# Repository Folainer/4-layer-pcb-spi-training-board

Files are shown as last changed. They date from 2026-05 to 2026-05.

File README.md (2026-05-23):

# 4-Layer SPI-Based Multi-Function PCB Design (Training Project)

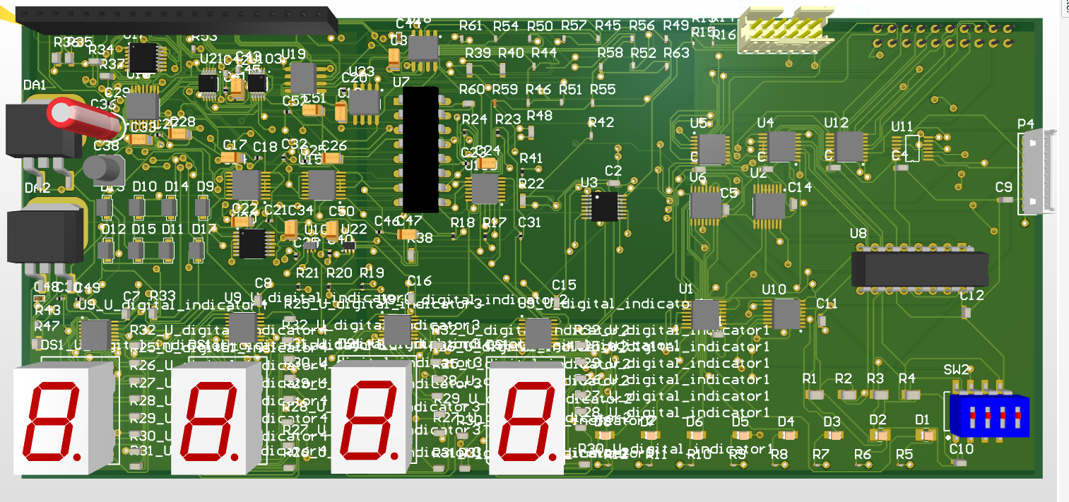
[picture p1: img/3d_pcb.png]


[Project Schematic (PDF)](./docs/Schematic%20PDF_[No%20Variations].pdf)

### Overview
This project presents the design of a **4-layer printed circuit board (PCB)** developed as a training platform for learning modern hardware design practices.

The board is designed to interface with an external SPI master device (conceptually) and integrates multiple digital and analog subsystems. The primary goal of this project is not a single application, but rather gaining hands-on experience in full-cycle PCB development.

---

### Features
- SPI-based communication interface (conceptual master-slave setup)
- LED and 7-segment display control
- Matrix keyboard input handling
- Shift registers integration
- Analog signal processing using operational amplifiers
- ADC (Analog-to-Digital Converter)
- DAC (Digital-to-Analog Converter)

---

### Hardware Architecture
The design combines both **digital logic (74HC series)** and **analog components**, including:
- Counters, shift registers, multiplexers
- Operational amplifiers (MCP600x series)
- ADC (ADS8867)
- DAC (TLV5604)

The system is modular and demonstrates interaction between multiple subsystems via SPI.

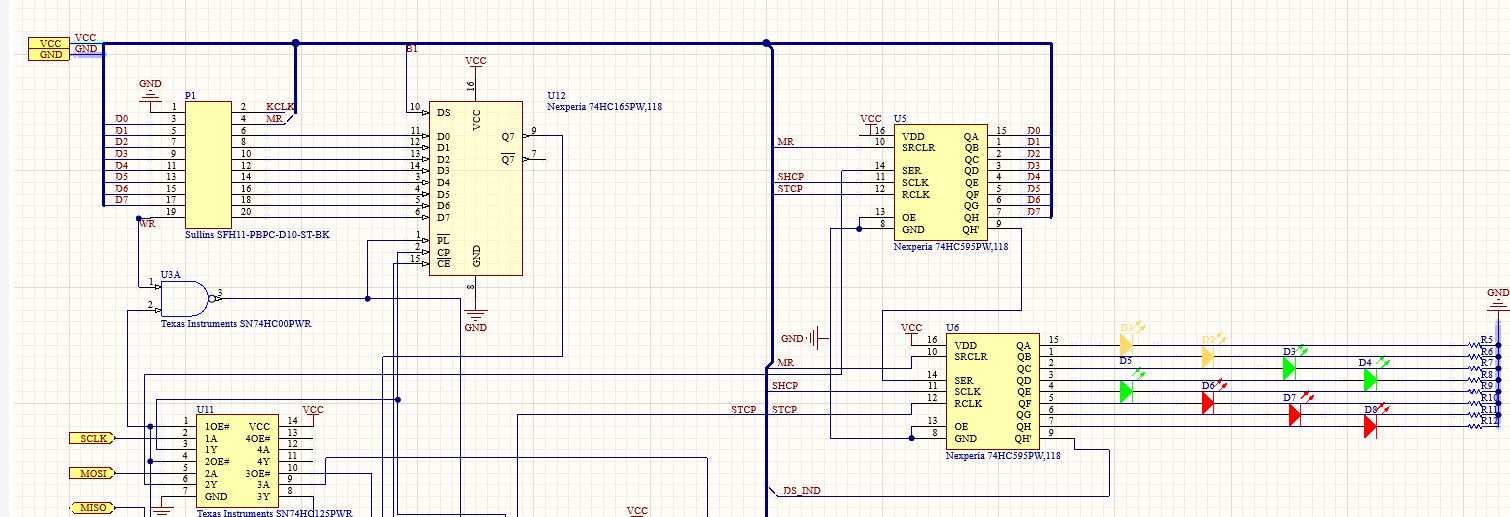
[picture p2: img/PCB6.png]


---

### PCB Design
- **4-layer PCB stackup**
    - Top Layer — signal routing
    - Inner Layer 1 — power plane (5V / 3.3V)
    - Inner Layer 2 — ground plane
    - Bottom Layer — signal routing
- Separation of **analog and digital domains**
- Star grounding technique (single-point ground connection)
- Power polygons for multiple voltage domains
- Priority-based manual routing for critical signals
- Basic impedance awareness and EMI reduction techniques

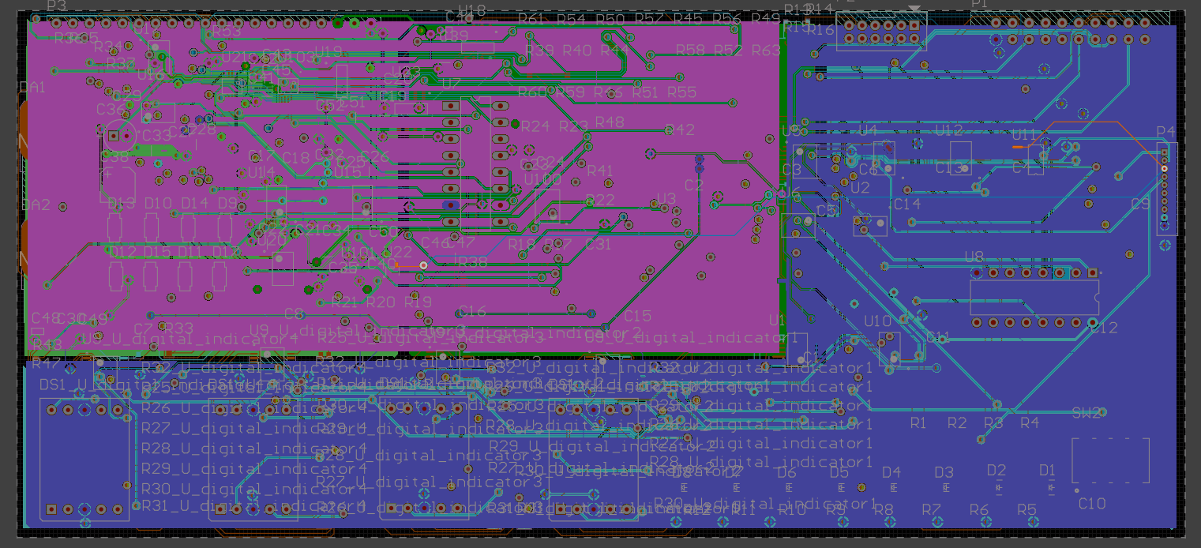
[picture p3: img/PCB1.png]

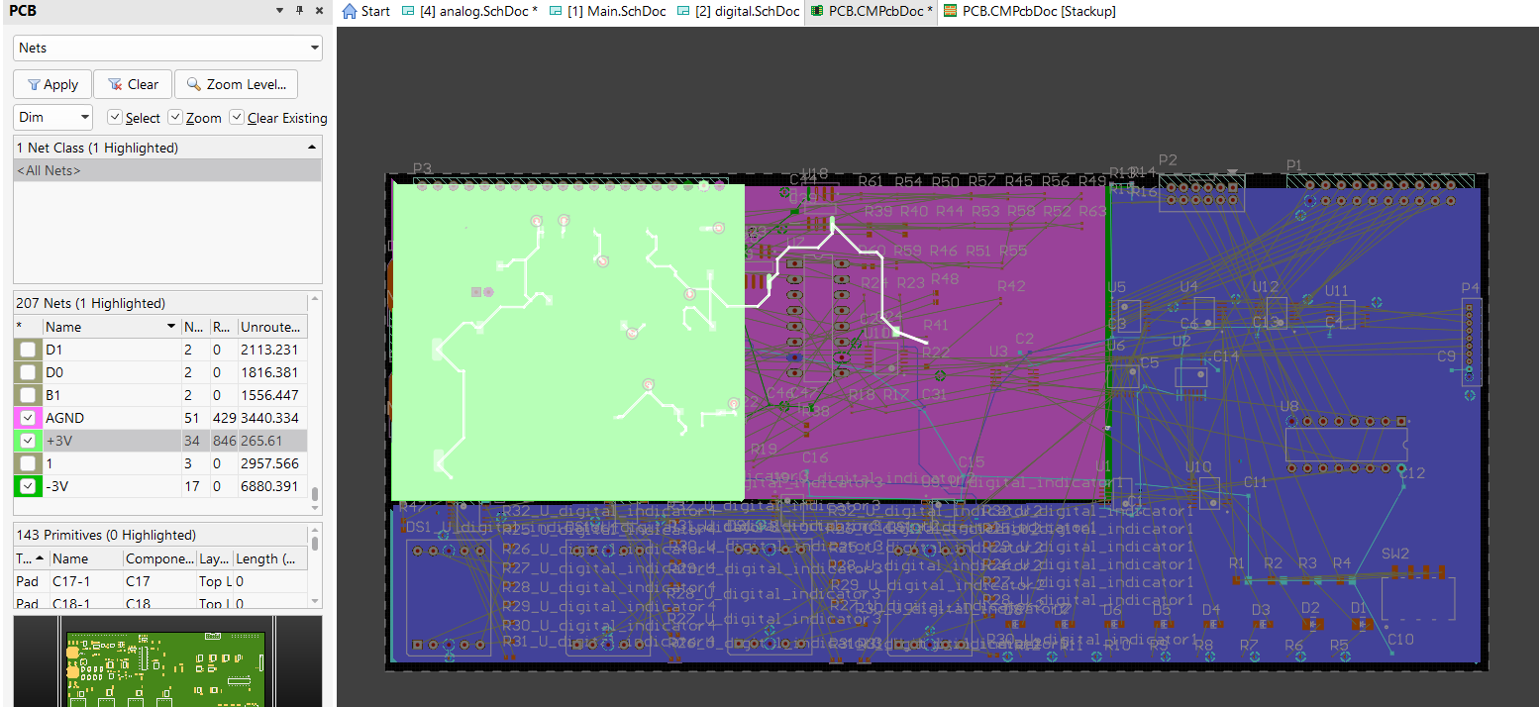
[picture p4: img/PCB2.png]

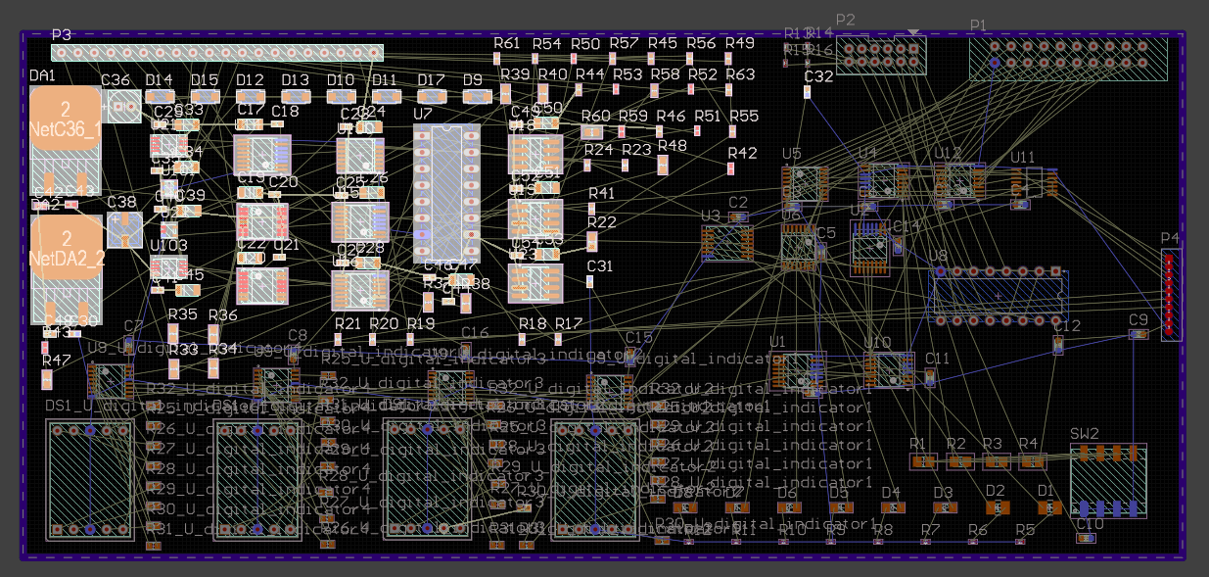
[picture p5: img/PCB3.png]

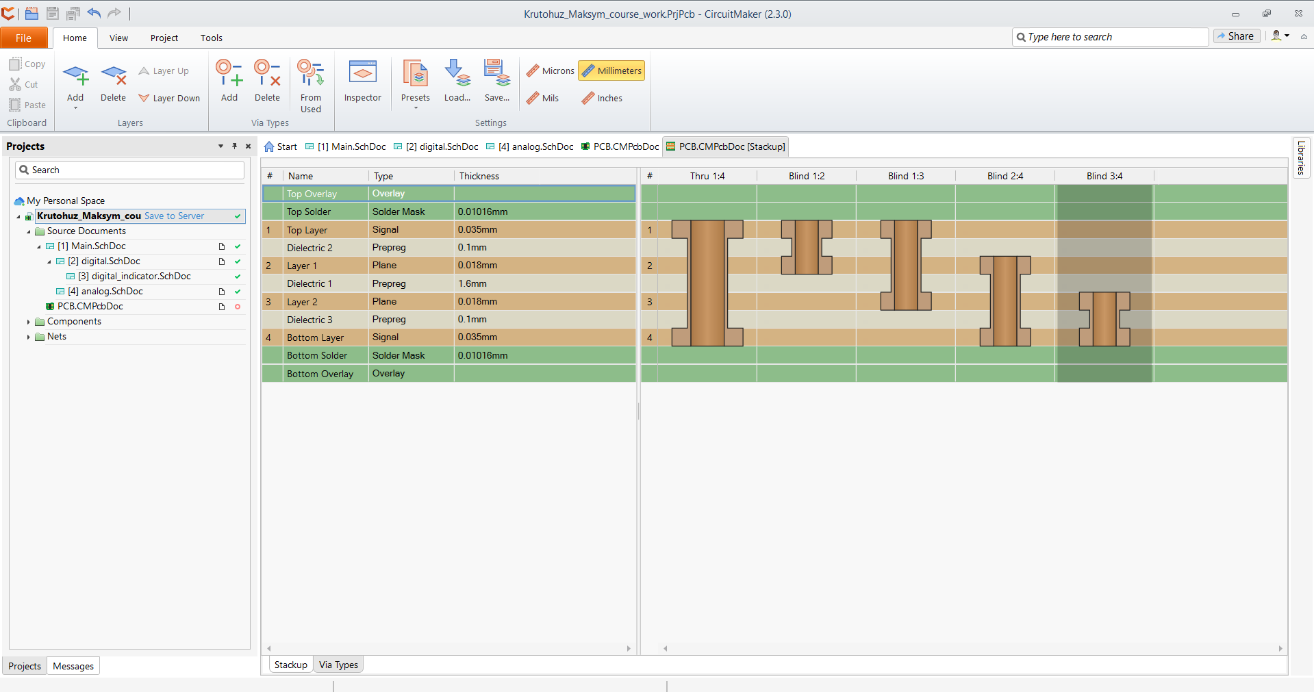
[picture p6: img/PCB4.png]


---

### Tools Used
- Altium CircuitMaker
- Simulation: Micro-Cap
- Component sourcing: Digi-Key, Mouser

---

### Project Outputs
- [Schematic design](./docs/Schematic%20PDF_[No%20Variations].pdf)
- PCB layout (4 layers)
- 3D model of the board
- Gerber files for manufacturing

---

### Repository structure

```bash
.
├── LICENSE
├── README.md
├── docs
│   ├── Assembly Drawings_[No Variations].pdf
│   ├── BOM_[No Variations].csv
│   ├── Schematic PDF_[No Variations].pdf
│   └── Крутогуз КВ-22.pdf
├── img
│   ├── 3d_pcb.png
│   ├── PCB1.png
│   ⋮
│   └── PCB6.png
└── src
    ├── Gerber for PCB.CMPcbDoc
    │   ├── NC Drill
    │   │   ├── PCB.CMPcbDoc.DRR
    │   │   ⋮
    │   │   └── PCB.CMPcbDoc.TXT
    │   ├── PCB.CMPcbDoc-macro.APR_LIB
    │   ⋮
    │   ├── PCB.CMPcbDoc_Profile.gbr
    │   └── Status Report.Txt
    ├── step1.cir
    ⋮
    └── step7.cir

```

---

### Learning Outcomes
- Full-cycle PCB design workflow
- Signal routing strategies (manual vs auto)
- Power distribution and grounding techniques
- Integration of analog and digital circuits
- Practical experience with SPI-based system design

---

### Notes
This is a **training project** and was not physically manufactured. The design simulates a real-world hardware system and focuses on engineering practices rather than a specific end-product.

---

**Watch the project videos on YouTube:**
🇺🇦 [Ukrainian version](https://www.youtube.com/watch?v=V8oYccrw_HA&t=2s)

---

### Final results


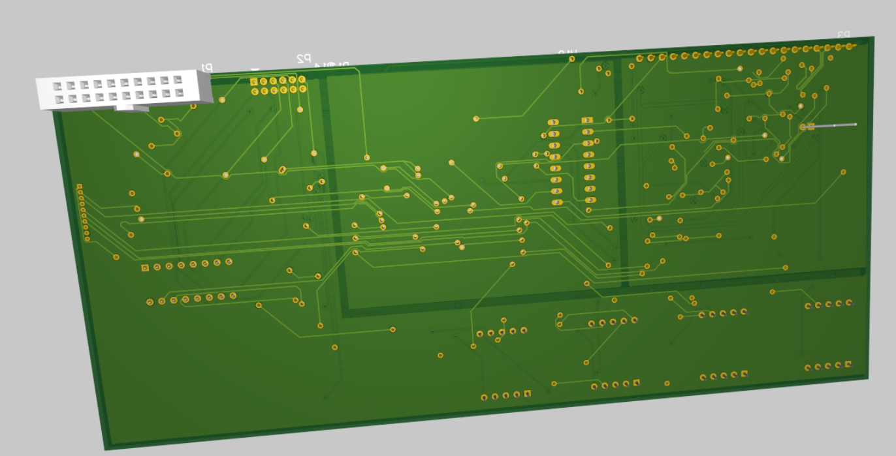
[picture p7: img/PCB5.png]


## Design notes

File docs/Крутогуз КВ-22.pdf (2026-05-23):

НАЦІОНАЛЬНИЙ ТЕХНІЧНИЙ УНІВЕРСИТЕТ УКРАЇНИ «КИЇВСЬКИЙ ПОЛІТЕХНІЧНИЙ ІНСТИТУТ ім. Ігоря Сікорського»

ФАКУЛЬТЕТ ПРИКЛАДНОЇ МАТЕМАТИКИ

КАФЕДРА СИСТЕМНОГО ПРОГРАМУВАННЯ ТА СПЕЦІАЛІЗОВАНИХ КОМП’ЮТЕРНИХ СИСТЕМ

# Курсова робота

### з дисципліни «Комп’ютерна електроніка» Тема: «Проєктування і моделювання схеми та розробка друкованої плати шини SPI»

Київ - 2025

Виконав Студент ІІІ курсу ФПМ, групи КВ-22 Крутогуз М.І.
Керівник Доцент кафедри СПСКС
Щербина О.А.

Зміст

2. РОЗРОБКА ТА МОДЕЛЮВАННЯ ВХІДНОГО ПОРТУ ШИНИ SPI.....6
3. РОЗРОБКА ТА МОДЕЛЮВАННЯ ВИХІДНОГО ПОРТУ ШИНИ SPI 10
4. РОЗРОБКА ТА МОДЕЛЮВАННЯ МАТРИЧНОЇ КЛАВІАТУРИ........15
6. МОДЕЛЮВАННЯ ЦИФРО-АНАЛОГОВОГО ПЕРЕТВОРЮВАЧА....21
7. МОДЕЛЮВАННЯ АНАЛОГО-ЦИФРОВОГО ПЕРЕТВОРЮВАЧА....24
8. РОЗРОБКА І МОДЕЛЮВАННЯ СХЕМИ АНАЛОГОВИХ

ЗАВДАННЯ НА КУРСОВУ РОБОТУ

Спроєктувати схему і друковану плату шини SPI, що містить перелічені нижче елементи.

1) Вхідні 74HC165 і вихідні 74HC595 регістри зсуву.
2) Перший роз’єм типу header або подібний, що має не менше 20 контактів.
3) 8 цифрових входів і вхід WR синхронізації їх запису в регістр, що поступають у схему через перший роз’єм.
4) 4 цифрових входів, значення яких формуються встановленими на платі перемикачами типу Electromechanical – Switches - DIP Switches.
5) 8 цифрових виходів, що видаються зі схеми через перший роз’єм.
6) 8 цифрових виходів, стан яких відображається встановленими на схемі світлодіодами зеленого, жовтого і червоного кольору, розташованими на платі в послідовності ЖЖЗЗЗЧЧЧ.
7) 4 семи- або восьмисегментних індикаторів цифр, зв’язаних з вихідними регістрами шини SPI.
8) Схему опитування матричної клавіатури, яка складається з 8 рядків і 4 колонок, що підключаються до неї через другий роз’єм. Ця схема має записувати у вхідний регістр шини SPI номер натиснутої клавіші.
9) 4 аналогових виходів, напруги в яких формуються підключеними до шини SPI цифро-аналоговими перетворювачами (ЦАП) розрядністю 10 бітів і видаються на третій роз’єм за допомогою диференційних пар.
10) 2 аналогових входів, що приймаються на третій роз’єм і диференційними парами сполучаються з аналого-цифровими перетворювачами (АЦП) розрядністю 16 бітів, які виводять результат перетворення у шину SPI.
11) Схему на операційних підсилювачах, яка формує вихідну напругу Z за формулою Z=A1*X1+A2*X2+B1*Y1+B2*Y2, де Х1, Х2 – напруги на першому і другому аналогових входах, Y1, Y2 – напруги на першому і другому аналогових виходах,

A1=-0,15; A2=0,25; B1=-0,11; B2=-0,18. Напруга Z диференційною парою виводиться на третій роз’єм, через який на плату ще подаються напруги живлення аналогових схем +3 В, -3 В і аналогове заземлення AGND.
12) Четвертий роз’єм, через який на плату поступають напруга живлення
цифрових | схем VCC=5 B і | цифрове | заземлення GND, | сигнали
шини SPI: SCLK, MOSI, MISO, | а | також | потрібна | кількість
сигналів Slave Select: SS0, SS1, SS2…
При побудові описаних вище схем використовувати мікросхеми у
корпусах | типу TSSOP | (SSOP), а | при | відсутності | в
базі Altium CircuitMaker компонента у такому корпусі, взяти найбільш подібний до нього.
Елементи індикації і перемикачі розташувати вздовж нижнього краю плати, перші три роз’єми – біля верхнього, а четвертий – біля правого краю плати.
Для реалізації проекту будемо в основному використовувати матеріали курсів комп’ютерної електроніки [1] [2].

### 1. ЗАГАЛЬНІ ВІДОМОСТІ ПРО ШИНУ SPI

Шина SPI це — шина за допомогою, якого пристрої можуть підключатися один до одного в зручним способом (рисунок 1.1). Один пристрій є головним і називається „майстром“, наприклад мікроконтролер, він може хотіти спілкуватися із іншими пристроями, наприклад із матричною клавіатури, чи виводити цифру на 7-сегментний індикатор, для цього, „майстер“ вибирає мікросхему, із якою він хоче поспілкуватися, надсилає туди сигнал SS. Один біт інформації передається кожний раз, коли годинник подає прямий динамічний сигнал SCLK (надсилається самим „майстром“). Інформація від „майстра“ до „підлеглого“ передається за допомогою лінії MOSI, а інформація від „підлеглого“ до „майстра“ передається за допомогою лінії MISO.

Рисунок 1.1 — Приклад використання шини SPI

Основні характеристики включають: повний дуплекс (можливе одночасне відправлення та отримання даних), швидкість передачі велика.

### 2. РОЗРОБКА ТА МОДЕЛЮВАННЯ ВХІДНОГО ПОРТУ ШИНИ SPI

74HC165 — це 8-розрядний зсувний регістр паралельного входу та послідовного виходу (рисунок 2.1). Він зазвичай використовується для розширення кількості вхідних контактів, доступних для мікроконтролера або інших цифрових пристроїв, шляхом зчитування кількох паралельних входів і їх послідовного зміщення за допомогою меншої кількості контактів. Опис виводів зсувного регістру бачимо в таблиці 2.1.

Рисунок 2.1 ‒ регістр зсуву 74HC165

Таблиця 2.1 - Детальний опис виходів мікросхеми 74HC165
Назва піну | Введення/ Виведення | Опис
A | Введення | Паралельне введення
B | Введення | Паралельне введення
C | Введення | Паралельне введення
CLK | Введення | Сигнал для зсуву даних на один біт
CLK INH | Введення | Дозвіл на зсув даних. Активний коли логічний сигнал нуля.
D | Введення | Паралельне введення
E | Введення | Паралельне введення
F | Введення | Паралельне введення
G | Введення | Паралельне введення
GND | ‒ | Земля

H | Введення | Паралельне введення
Q_h | Виведення | Послідовне виведення
#Q_h | Виведення | Інвертоване послідовне виведення

SER | Введення | Послідовне введення. Використовується в послідовному режимі для введення одного послідовного біту
SH/#LD | Введення | Режими роботи регістру зсуву. Якщо сигнал логічного нуля, то зчитується інформація паралельно, якщо сигнал логічної одиниці, то працює послідовний режим зсуву бітів, та заповнення із SER
V_cc | ‒ | Джерело живлення

На рисунку 2.2, бачимо, що на симуляції відбувається повний зсув бітів регістру (74HC165) з паралельного входу на послідовний вихід. Щодо самої діаграми на правій частині рисунку 2.2 бачимо, що перший сигнал виводить два нуля спочатку, оскільки ми закрили два перших ключа, а далі йде чергування, аж до останнього біту.

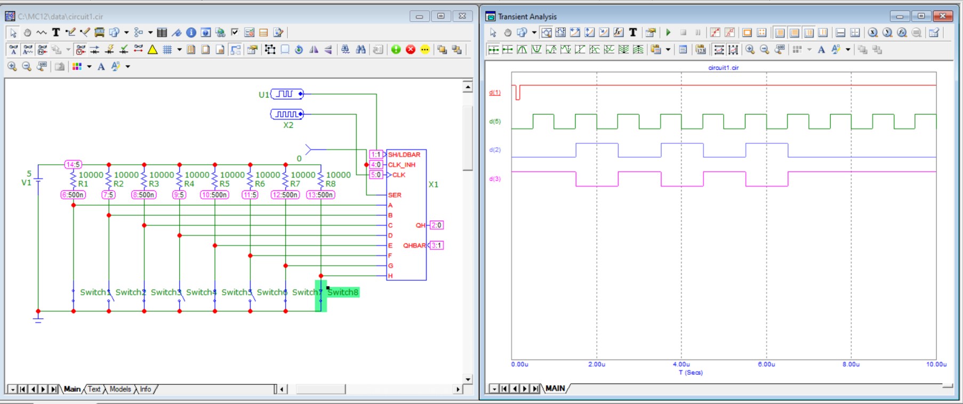
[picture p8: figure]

Рисунок 2.2 ‒ Симуляція сигналу для регістру зсуву Для вибору невеликого резистора, але з достатнім запасом надійності від перегрівання; обрахуємо потужність, яка споживається резистором та візьмемо із запасом (формула 2.1).

P=

U
R

=
10000

=0,0025=2,5 мВт(2.1)

Перейдемо до моделювання вхідного порту шини SPI. Для цього виведемо 8 паралельних бітів із першого роз’єму в перший регістр зсуву; а 4 бітів, які формуються від стану кнопок виведемо на другий регістр зсуву. Ці два регістри, з’єднані між собою і дані можуть передаватися через один сигнал виведення. Схему можна побачити на рисунку 2.3.

Малюнок 2.3 ‒ Схема порту шини SPI Далі додамо розв’язуючі конденсатори. Наймісткіший служить для джерела живлення, інші для окремої мікросхеми.

Також маємо на схемі буферний підсилювач, порти та логічний елемент. Буферний підсилювач, зменшує імпеданс вхідного сигналу, та надає змогу елементу перебувати у третьому стані. Порти потрібні для шини даних, які ми розробляємо, і перейдемо до них знову пізніше. Логічний елемент дозволяє налаштувати режими роботи регістру зсуву.

### 3. РОЗРОБКА ТА МОДЕЛЮВАННЯ ВИХІДНОГО ПОРТУ ШИНИ SPI

Перейдемо до моделювання вихідного порту шини SPI. Для цього будемо використовувати, 8-розрядний регістр зсуву із трьома станами [3]. Подивитися максимальні можливі струми для регістру можна на рисунку 3.1.

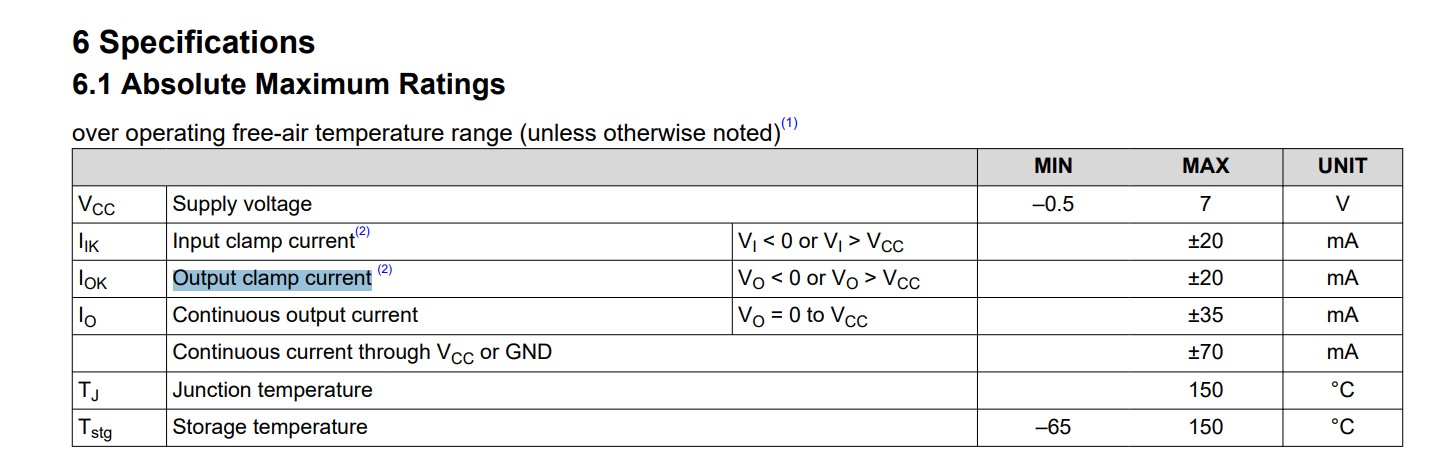
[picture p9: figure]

Рисунок 3.1 — Максимальні характеристики регістру зсуву

Знаходимо максимально допустимий струм в нашому випадку — 35мА.

Перейдемо до вибору світлодіодів за варіантом на сайті компанії mouser. Після налаштування необхідних фільтрів результати спостерігаємо на рисунку 3.2.

Рисунок 3.2 — Вибір світлодіодів на сайті mouser Після пошуку знаходження всіх необхідних світлодіодів у необхідній кількості, розміщення їх можна спостерігати на логічній схемі (рисунок 3.3).

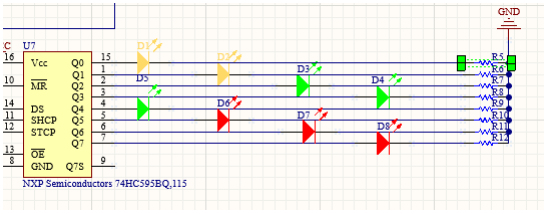
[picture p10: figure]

Рисунок 3.3 — Розміщення світлодіодів на схемі

Тепер, знайдемо опори резисторів для світлодіодів. Для цього використаємо програму Micro-Cap та зробимо там схему (рисунок 3.4). Спочатку почнемо із 1500 Ом та будемо перевіряти чи буде світлодіод світитися в залежності від кольору світлодіоду. Отже таким, чином можемо розрахувати необхідний опір для стабільного світіння світлодіодів в залежності від характеристик вибраних світлодіодів (необхідний струм для світіння).

Рисунок 3.4 — Перевірка роботи світлодіодів в залежності від опору резисторів

Тепер перейдемо до пошуку необхідного опору, поступово змінюючи опір резистору за номінальною таблицею E12. Можна побачити що на рисунку

3.5 струм недостатній для світіння світлодіодів. Змінивши опір знову до 1200 Ом, межа струму перетнулася та світлодіоди повинні світитися (рисунок 3.6).

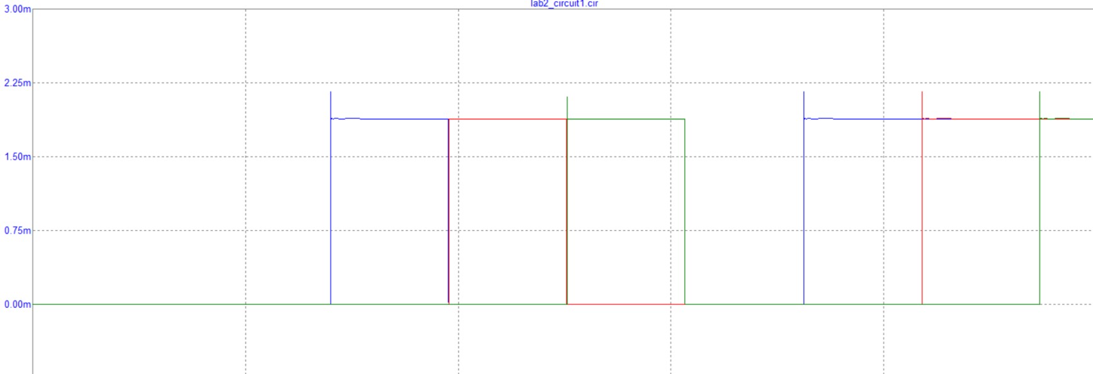
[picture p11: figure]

Рисунок 3.5 — Діаграма струмів світлодіодів із початковим опором резисторів

Рисунок 3.6 — Діаграма струмів світлодіодів із остаточним опором резисторів
Потужність обрахуємо за формулою 3.1. Оскільки резистор збільшує опір під час роботи, що спричиняє виділення ще більше потужності, то оберемо резистор приблизно із потужністю 20 мВт.

P=R⋅ I

2=1200⋅(2⋅10⁻³

)

2
=4800 мкВт(3.1)

Для того аби пересвідчитися, що світлодіоди дійсно світяться і світяться на потрібних позиціях (в залежності від замкнутих ключів), використаймо анімовані світлодіоди (рисунок 3.7). Що за 9 мс можна побачити світіння відповідних світлодіодів можна пересвідчитися на рисунку 3.8.

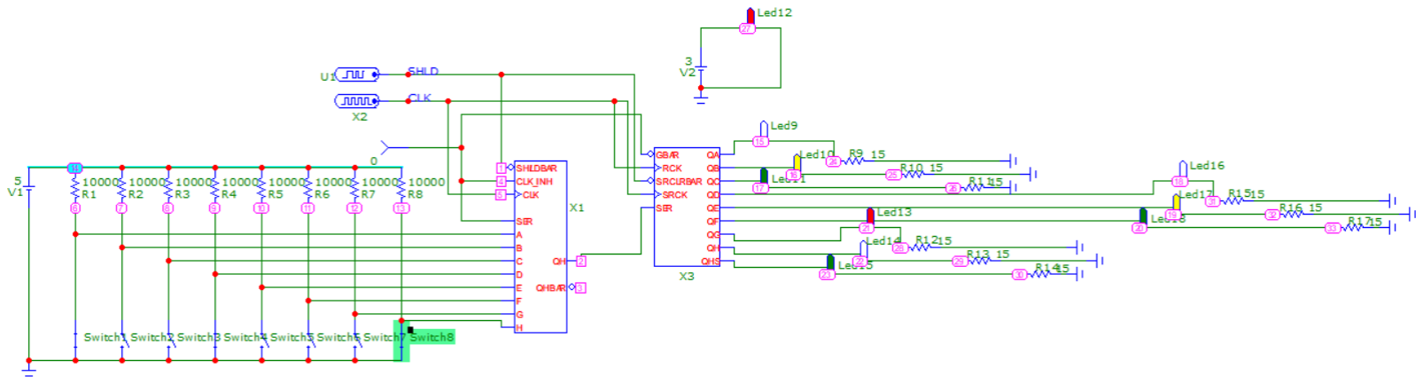
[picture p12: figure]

Рисунок 3.7 — Моделювання анімованих світлодіодів

Рисунок 3.8 — Діаграми сигналів на різних точках схеми
Вхід STCP (RCK) регістру зсуву є динамічним прямим. З’ясувати можемо за допомогою спроби підключення його різними чинами. Але врешті-решт Підключивши його відповідним чином до сигналу тактової частоти, то схема почала працювати належним чином. Оскільки від переходу тактової сигналу із 0 в 1 відбувається такт, і як висновок STCP (RCK) є динамічним прямим.

У цій частині курсової роботи реалізовано два регістри зсуву, що виконують перетворення послідовного коду в паралельний. Дані спочатку завантажуються в регістри защіпки, а потім виводяться на виходи. Виходи першого регістра підключено до роз’єму, а другого – до світлодіодів. Побачити розроблену схему можна на рисунку 3.8.

Серед важливих аспектів, треба бути обережними при виборі опору резисторів, аби світлодіоди не перегрілися. Якщо температура стане занадто високою, вони можуть перестати працювати, особливо це актуально в країнах із жарким кліматом.

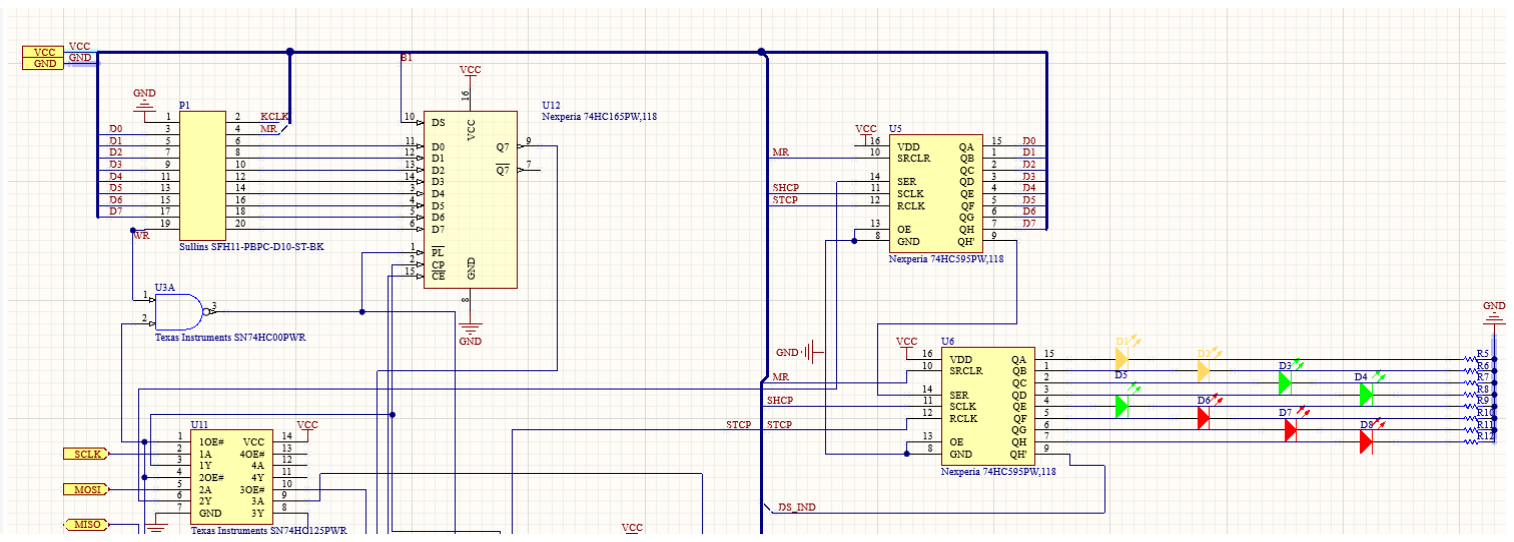
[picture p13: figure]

Рисунок 3.8 — Розроблена схема для виводу інформацію на світлодіоди різного кольору

### 4. РОЗРОБКА ТА МОДЕЛЮВАННЯ МАТРИЧНОЇ КЛАВІАТУРИ

Матрична клавіатура складається із рядків та стовпців. Замість того, аби мати роз’єми на всіх клавіші, така клавіатура може спростити складність із M*N до M + N роз’ємів. Для цього на кожний рядок по черзі подається земля, і ми зчитуємо поточне значення на стовпці, тобто ми можемо знати рядок та стовпець де натиснута клавіша.

Спробуємо реалізувати таку матричну клавіатуру. Для цього нам буде потрібний лічильник, дешифратор із інверсними входами, мультиплексор, регістр зсуву та сама клавіатура.
Нумерація клавіш ведеться зверху вниз та з права наліво. Можемо побачити, що останні три натискання на клавіші оброблюються як слід (рисунок 4.1). Але слід зазначити, що якщо зажати клавішу на інших рядах може попасти земля на інший рядок, і буде неможливо відрізнити на якому рядку була натиснена клавіша. Також можемо побачити цю помилку на рисунку 4.2. Замість того аби відобразити чотири клавіші, в результаті шість.

Рисунок 4.1 - Тестування матричної клавіатури 4x4 Як висновок, якщо натискаймо декілька клавіш на одному рядку, і якщо спробуємо натиснути іншу клавішу на іншому рядку при умові що на цьому стовпцю вже натиснена клавіша на іншому рядку, то клавіші спрацюють хибно, а значення всіх, буде перенесено також на цей рядок, якщо навіть не натиснені всі клавіші на цих позиціях.

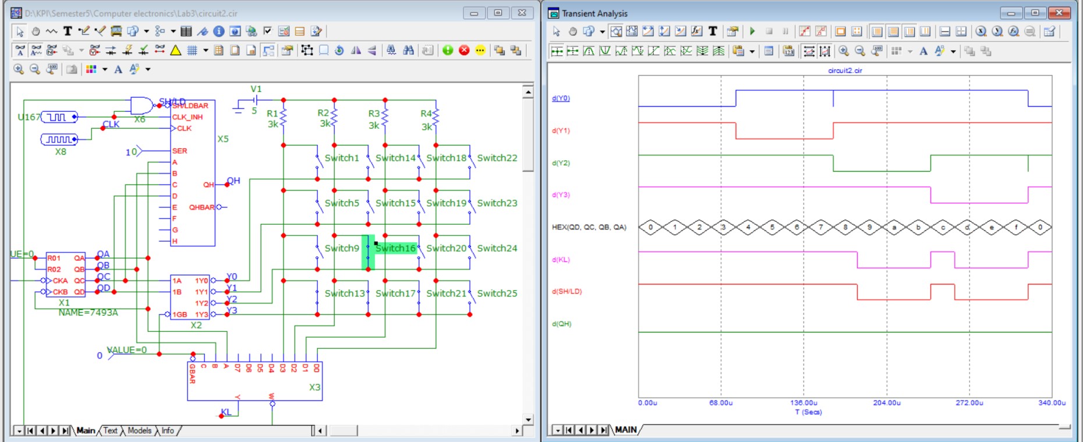
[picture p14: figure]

Рисунок 4.2 — Демонстрація помилкового опитування клавіш Тепер спробуємо додати діоди до схеми та замкнути ключі як і в попередньому варіанті. На рисунку 4.3 бачимо, що опитування клавіш пройшло правильно із чотирьох було чотири спрацювання (попередня помилка була виправлена).

Рисунок 4.3 — Демонстрація правильного опитування клавіш Перейдемо до реалізації матричної клавіатури в програмі Altium CircuitMaker. На побудовані схемі (рисунок 4.4) можна побачити зліва лічильник, який переходить на наступну ітерацію в залежності сигналу KCLK. Далі сигнали переходять до дешифраторів. Схема побудована таким чином, що для виведення восьми бітів замість чотирьох із дешифраторів, використано два дешифратори, за допомогою одного біту із лічильника кожні чотири ітерації відбувається почергове вимкнення одного із дешифраторів. Тобто, врешті-решт, кожної ітерації лічильника будемо мати одну землю на виході. Далі ці сигнали передаються на роз’єм.
Справа на схемі видно, інший лічильник, мультиплексер та регістр зсуву. Після кожного вимикання дешифратора подається сигнал на інший лічильник. Якщо, клавіша була натиснута регістр зсуву запам’ятає номер клавіші.

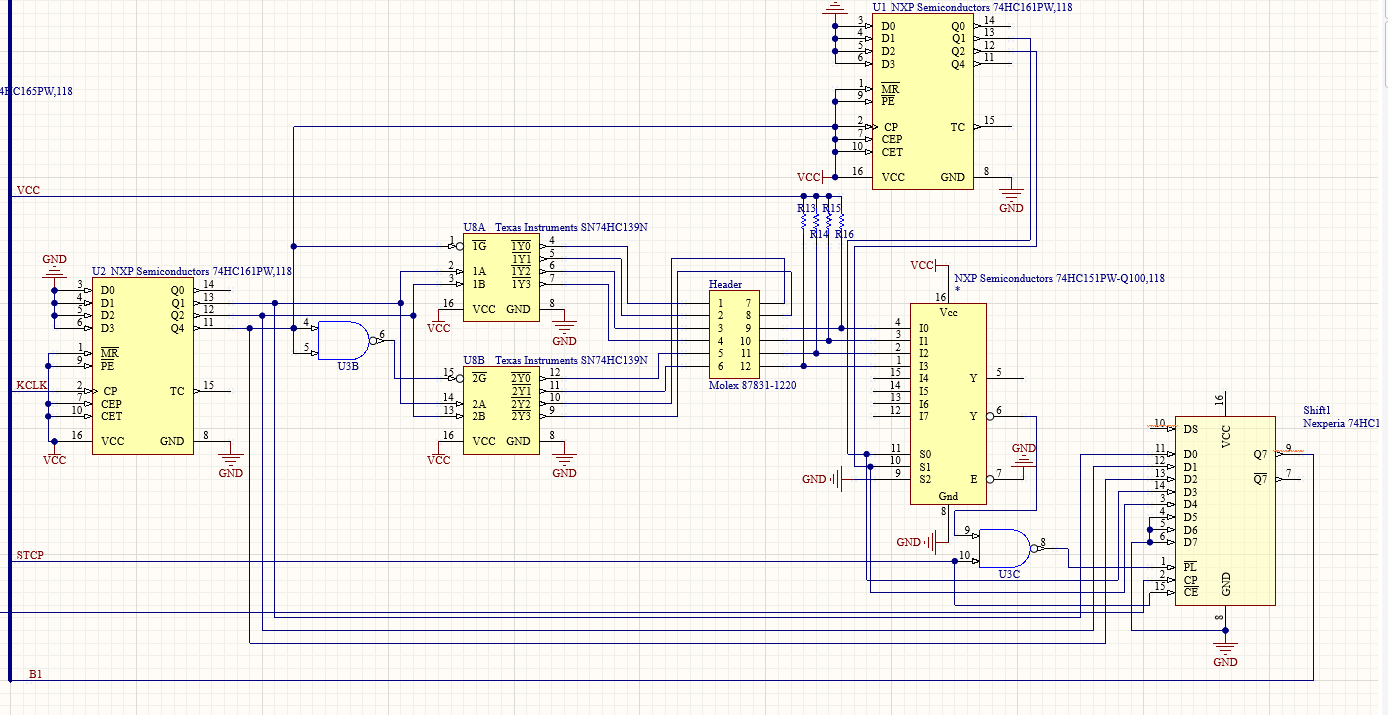
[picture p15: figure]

Рисунок 4.4 — Побудована схема опитування матричної клавіатури

### 5. РОЗРОБКА ТА МОДЕЛЮВАННЯ ІНДИКАТОРА ЦИФРИ

Для розробки цифрового індикатора для плати, про моделюємо цифровий індикатор в програмі Micro-Cap. Подамо на ключі сигнали так, аби отримати цифру „2“ (рисунок 5.1). Діаграму сигналів можна побачити на рисунку 5.2.

Рисунок 5.1 — Симуляція „2“ на 7-сегментному дисплеї

Рисунок 5.2 — Діаграма сигналів під час симуляції „2“

Тепер зробимо ті самі ж дія, але для цифри „3“ (рисунок 5.3, рисунок 5.4).

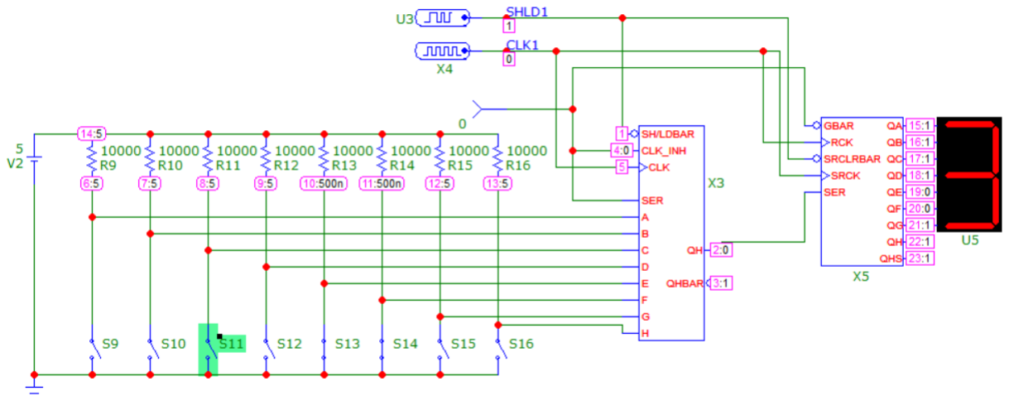
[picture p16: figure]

Рисунок 5.3 — Симуляція „2“ на 7-сегментному дисплеї

Рисунок 5.4 — Діаграма сигналів під час симуляції „3“

Після симуляції 7 сегментного дисплею, можемо переходить для його реалізації на платі. Спочатку перевіримо допустимі струми на регістрі зсуву (рисунок 5.5) [4]. Також перевіримо необхідний струм для світіння 7 сегментного дисплею (рисунок 5.6) [5]. Максимальний струм індикатора не перевищує струм у 74HC595.

Рисунок 5.5 — Струми на регістрі зсуву

Рисунок 5.6 — Прямий струм для 7-сегментного дисплея

Щодо резистору всередині індикатора, інформація не була знайдена в документації та щодо опору індикатора не було нічого написано. Отже, опір для резистору обрахуємо за такою формулою 5.1.

R=

V supply−V f
If

=

5−1,8
10⋅10⁻³=320Ом→330Ом(5.1)

Для більш швидкого та зручного розміщення чотирьох індикаторів, створимо новий схемний файл та спроектуємо логічну частину (рисунок 5.7), яка буде керувати за відображення одної цифри. В основному цифровому файлі додамо цю схему використовуючи символьний аркуш (рисунок 5.8).

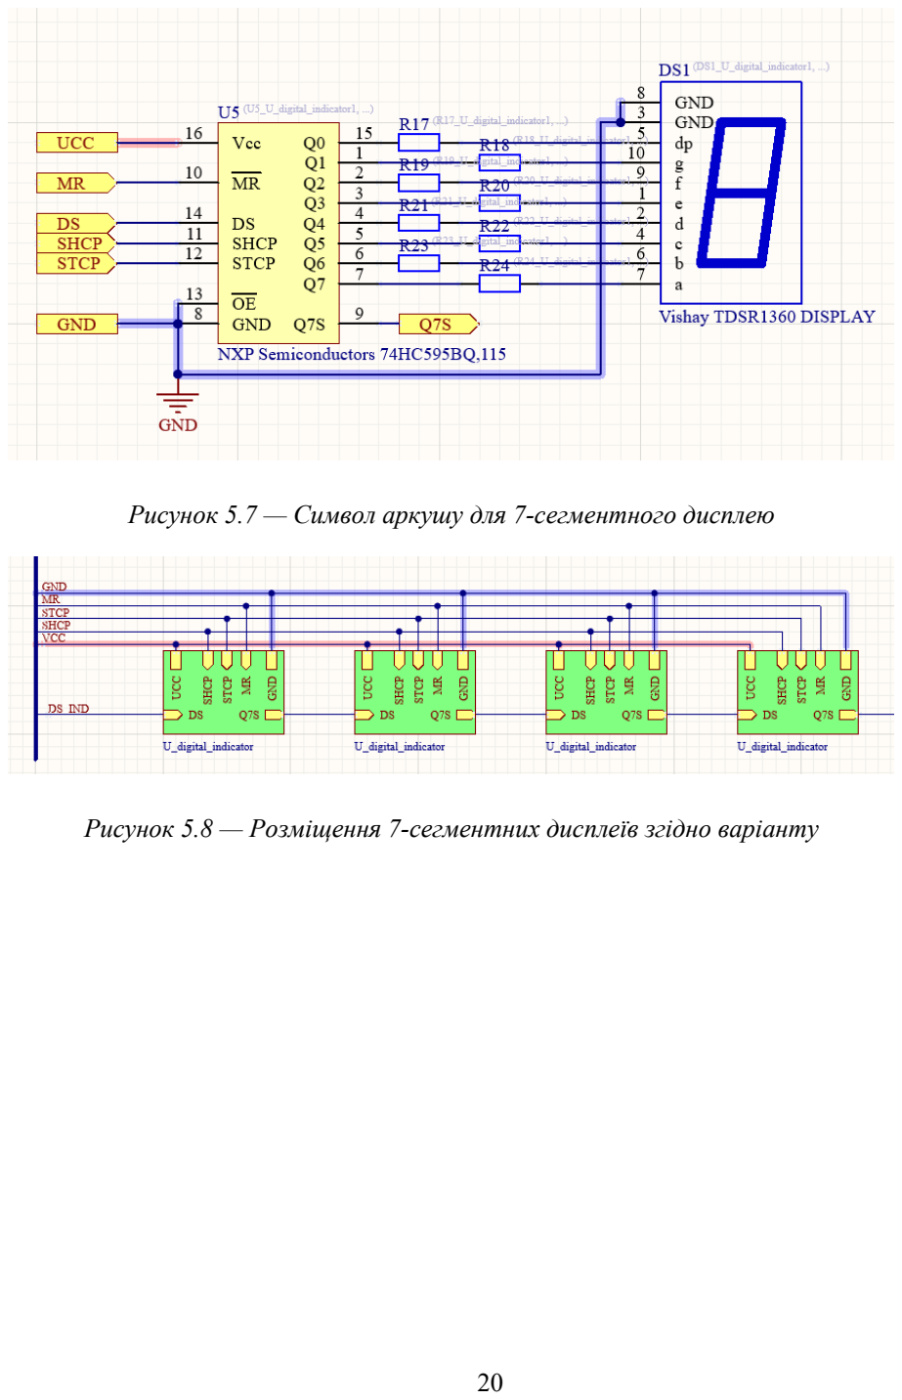
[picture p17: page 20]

Рисунок 5.7 — Символ аркушу для 7-сегментного дисплею

Рисунок 5.8 — Розміщення 7-сегментних дисплеїв згідно варіанту

### 6. МОДЕЛЮВАННЯ ЦИФРО-АНАЛОГОВОГО ПЕРЕТВОРЮВАЧА

Для проектування ЦАП на друкованій платі, промоделюємо ЦАП в програмі Micro-Cap. На рисунку 6.1, можна побачити, що біти подаються паралельно на ЦАП, які згодом перетворюються на аналоговий сигнал, величина якого зображена на схемі. Діаграма сигналів схеми зображена на рисунку 6.2.

Рисунок 6.1 — Моделювання цифро-аналогового перетворювача

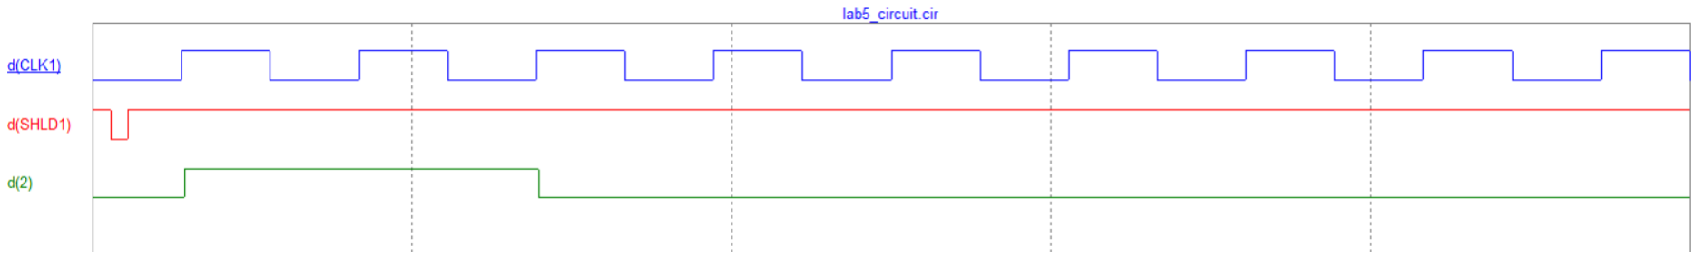
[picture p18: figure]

Рисунок 6.2 — Діаграма сигналів ЦАП Далі обираємо справжній ЦАП, який розмістимо на друкованій платі. Це буде 10-розрядний ЦАП, якого основний опис зображений на рисунку 6.3. Також на цьому рисунку зображена мікросхема та її виводи по їх номерах. На рисунку 6.4 можна побачити всі контакти вибраного цифро-аналогового перетворювача та для чого ці контакти можуть використовуватися.

Рисунок 6.3 — Основний опис вибраного ЦАП

Рисунок 6.4 — Опис використання виводів вибраного ЦАП

Спочатку перетворимо напругу із 5 вольт до 3 вольт за умови якщо є нуль на порті SS1, SS2,…. Завдяки логічної функції І, перетворювач напруг може бути ввімкнений або вимкнений.

Далі підключаємо виходи відповідно інформації в „Data sheets“. Вхід FS вимагає додати ще декілька мікросхем, аби поділити частоту на 40, та при 40 скинути лічильник і почати рахунок спочатку, тому будемо скидати значення обох лічильників якщо відповідні біти „1“.

В решті-решт у вибраному ЦАП є виходи для чотирьох аналогових напруг, тобто додамо сигналів для вибору мікросхеми (slave select) на один менше ніж у прикладі курсової роботи.

Результат проектування цього етапу зображений на рисунку 6.5.

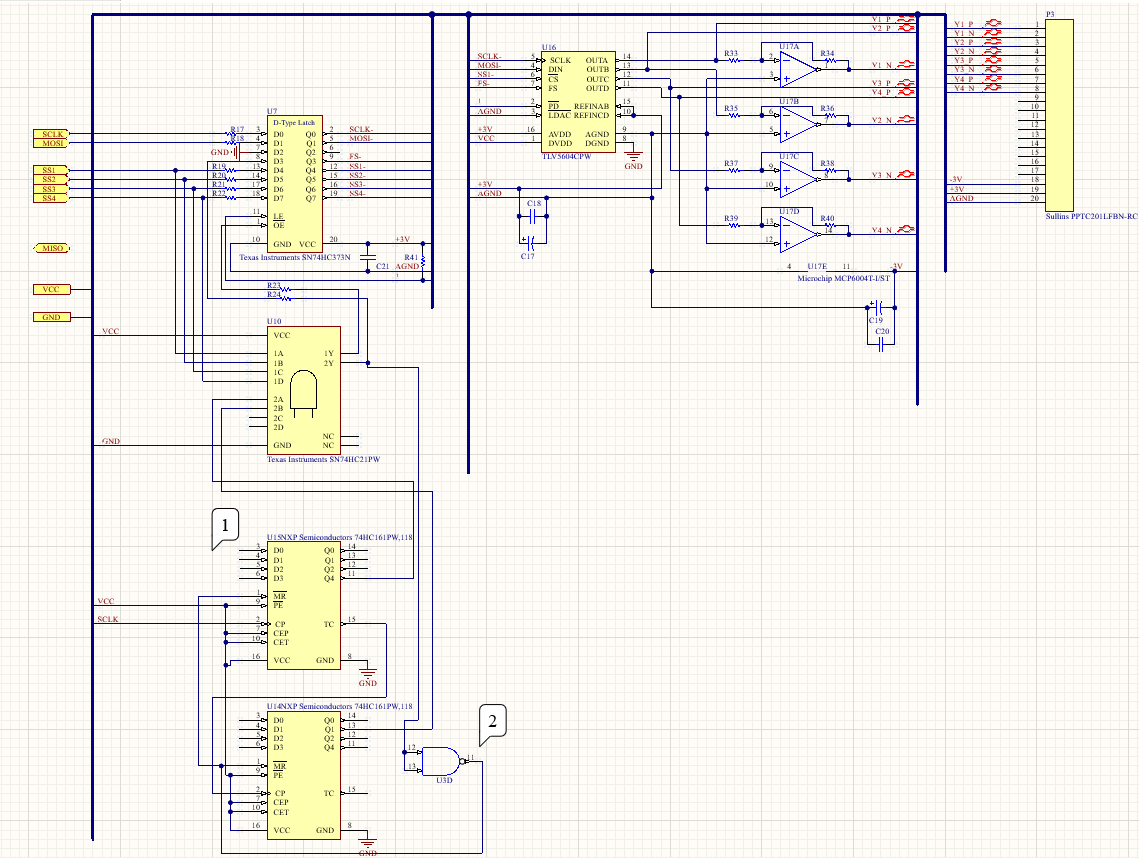
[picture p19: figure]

Рисунок 6.5 — Проектування схеми з використанням ЦАП

### 7. МОДЕЛЮВАННЯ АНАЛОГО-ЦИФРОВОГО ПЕРЕТВОРЮВАЧА

Перейдемо до проектування аналого-цифрового перетворювача. Спочатку зробимо симуляцію його роботи в програмі Micro-Cap (рисунок 7.1). Для цього підключимо опорну опору та аналоговий сигнал, який хочемо перетворювати в цифровий код. Після отримання послідовного, перетворимо його в послідовний, використовуючи регістр зсуву. Діаграму сигналів схеми можна побачити на рисунку 7.2.

Рисунок 7.1 — Підключення АЦП з вхідною напругою 3В

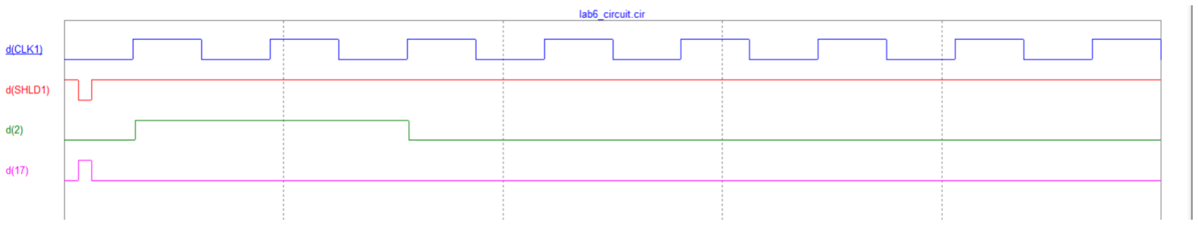
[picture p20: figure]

Рисунок 7.2 — Часові характеристики для 3В На попередніх малюнках, було зображено аналоговий сигнал та діаграму для 3 вольт. Тепер візьмемо аналоговий сигнал з напругою 5 вольт. Схему із підключення 3 вольт до АЦП можна побачити на рисунку 7.3. Діаграма часових характеристик для цієї напруги зображена на рисунку 7.4.

Рисунок 7.3 — Підключення АЦП з вхідною напругою 5В

Рисунок 7.4 — Часові характеристики для 5В Тепер перейдемо до ознайомлення із характеристиками із АЦП, який розмістимо на друковану плату. По-перше, маємо схему, яку повинні підключити до виходу результату (рисунок 7.5). По-друге, маємо діаграму сигналів послідовного інтерфейсу (рисунок 7.6). По-третє, на рисунку 7.7 зображено виводи мікросхеми та їх номера. І на останок, маємо назви виводів мікросхеми і пояснення щодо їх використання (рисунок 7.8).

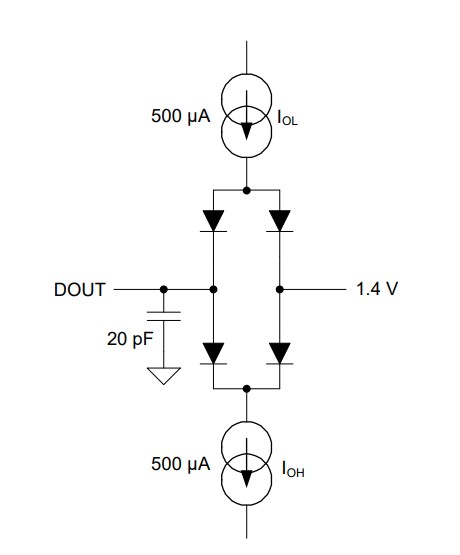
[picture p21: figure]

Рисунок 7.5 — Схема підключення виходу результату до АЦП

Рисунок 7.6 — Часова діаграма послідовного інтерфейсу

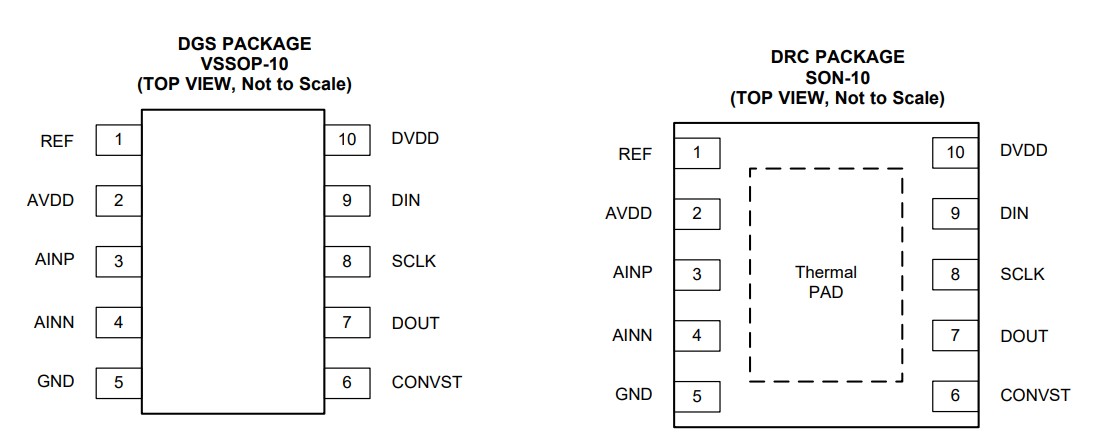
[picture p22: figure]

Рисунок 7.7 — Базове підключення АЦП Для стабілізації виходу результату в АЦП, потрібно сформувати напругу та струм на певному рівні. Почнемо обрахунки із напруги. Для цього буде використовувати формулу, яка зображена на рисунку 7.9. Для знаходження опорів резисторів один встановлюємо довільним чином, інший виводиться із попередньої формули. Схема підключення регульованого стабілізатора напруги в режимі стабілізації напруги зображена на рисунку 7.10.

Рисунок 7.8 — Опис усіх виводів АЦП

Рисунок 7.9 — Обрахунки опорів для регульовано регулятора напруги(LM317 )

Рисунок 7.10 — Скріншот відео YouTube щодо підключення резистора в режимі стабілізації напруги для LM317 Тому використовуючи схему та формулу, що були наведені зверху, отримуємо результати, які зображені на рисунку 7.11.

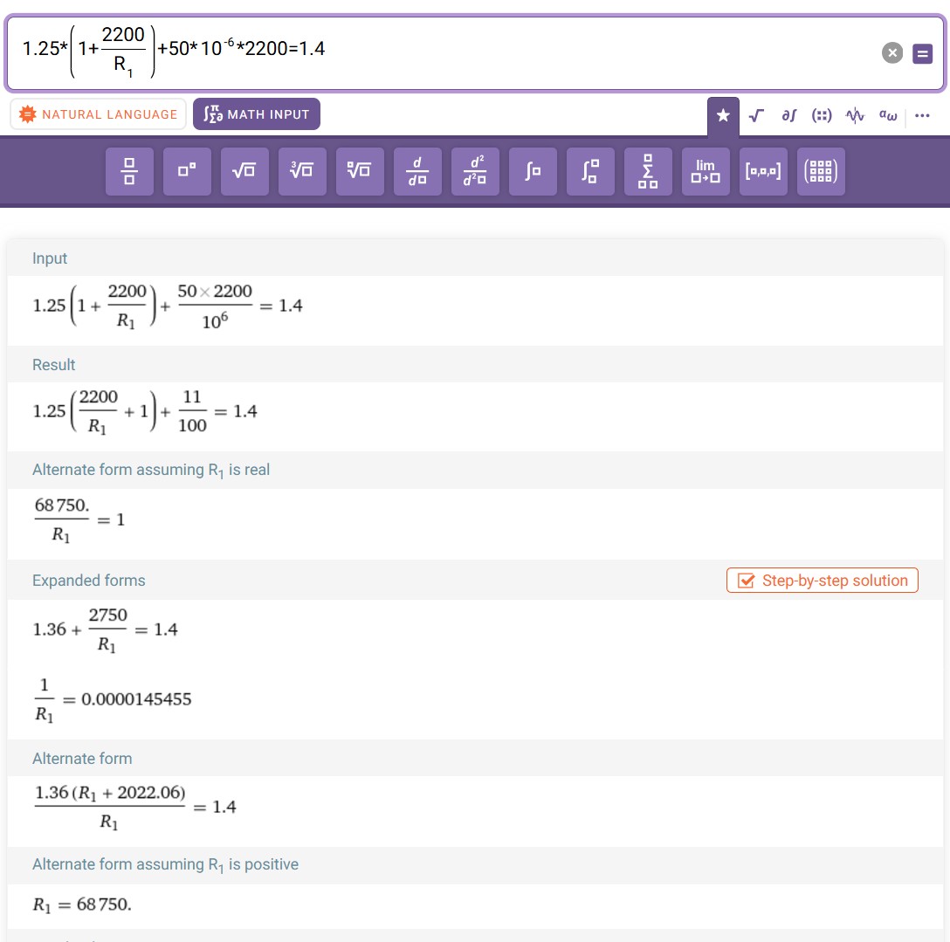
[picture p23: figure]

Рисунок 7.11 — Обчислення значень опорів для стабілізації напруги до 1.4В Як стабілізувати напругу вже знаємо, тому перейдемо до того як стабілізувати струм. Для цього використаймо той ж самий регульований стабілізатор напруги, але вже в іншому режим — стабілізації струму. На рисунку 7.12 можна побачити схему підключення та приклад обрахунку опору резистору для стабілізації струму. Використовуючи цей приклад, знайдемо необхідний резистор для стабілізації струму на необхідному рівні. Розрахунки зображені на рисунку 7.13.

Рисунок 7.12— Метод подальших обрахунків для стабілізації струму

Рисунок 7.13 — Обрахунок опору для LM317 в режимі стабілізації струму 500мкА
Отже можемо підбити підсумки щодо розробленої логічної схеми (рисунок 7.14 та рисунок 7.15).

По-перше в роботів використовувався 16 бітовий АЦП, в якому як в інший аналогових схемах живлення +3В та потребує розв’язуючі конденсатори для стабілізації живлення.

По-друге, схема стабілізації виходу Dout (вихід результату АЦП) потребує подавати на ділянки схеми певне конкретне значення напруги та струму для цього використовувався LM317 (регульований регулятор напруги). Для струму та напруги було доданий свій регульований регулятор напруги. Способи обрахунків елементів схеми стабілізації було пояснено раніше. Для отримання струму протилежного знаку використовувалися операційні підсилювачі в інвертному режимі. Використання саме одного стабілізатора напруги та одного стабілізатора струму для двох виходів Dout, пояснюється тим, що регульовані регулятори напруги мають зворотний зв’язок стабілізації свого стану, а оскільки вони були розраховані на певну напругу та струм, то зі збільшенням або зменшення навантаження їхні значення повинні залишатися незмінними(від’ємний зворотній зв’язок).

По-третє, оскільки в LM317, напруга вирівнювання сягає 1.25В, тому діоди були вибрані з більшою напругою ніж 1.25В.

І на останок, було перетворено MISO із 3В до 5В та подано на відповідний порт, який спрацьовує коли кристал вибраний.

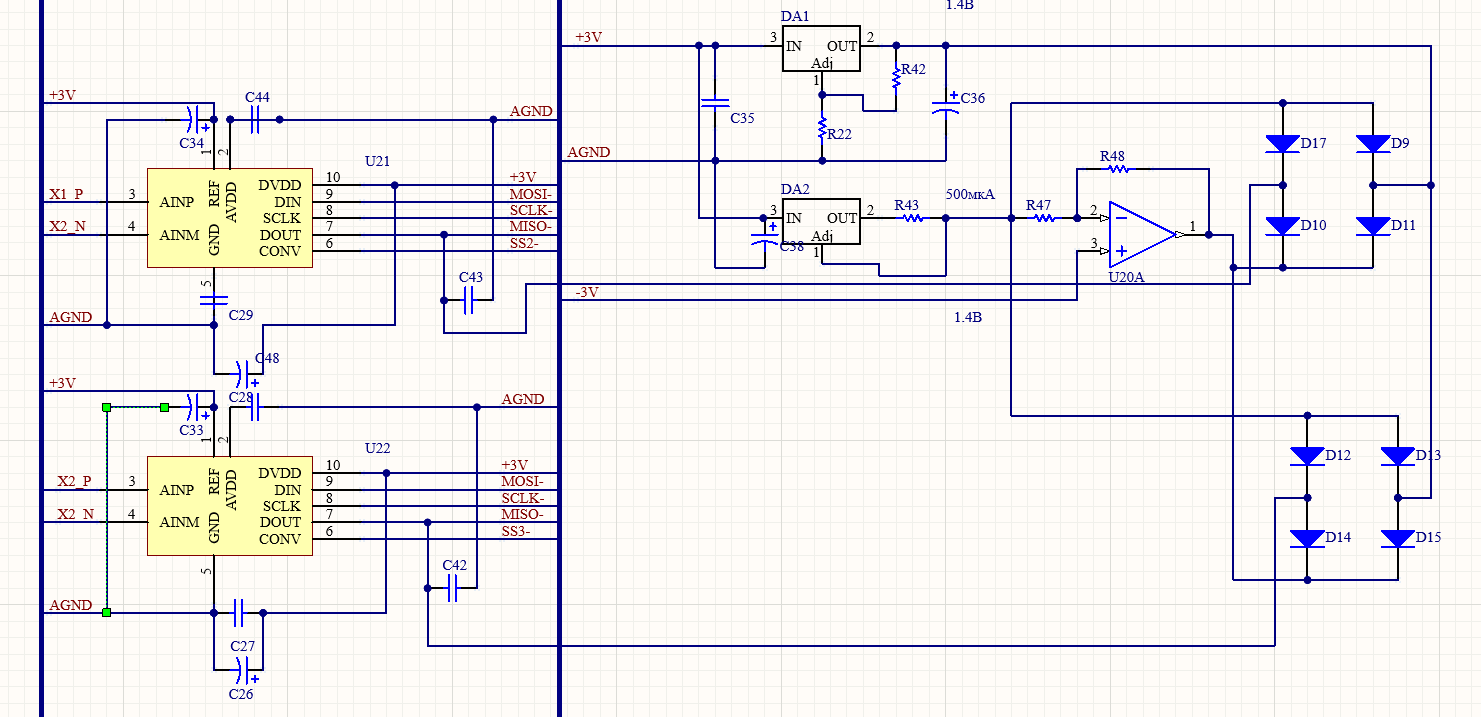
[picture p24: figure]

Рисунок 7.14 — Перша частина схеми виконаної роботи по АЦП

Рисунок 7.15— Друга частина схеми виконаної роботи по АЦП

### 8. РОЗРОБКА І МОДЕЛЮВАННЯ СХЕМИ АНАЛОГОВИХ

ОБЧИСЛЕНЬ

Перейдемо до розробки аналогових обчислень, для цього промоделюємо аналогові обчислення в програмі (обчислення формули Z=-0,15*X1+0,25*X2+-0,11*Y1+-0,18*Y2) Micro-Cap (рисунок 8.1).

Для цього були використанні підсилювачі у двох режимах: в режимі віднімання та режимі додавання. Перший режим, використовується для входів X1 та X2 – перетворює сигнал диференційної пари на позитивний сигнал; щодо входів Y1 та Y2 вони не використовують операційний підсилювач в режимі віднімання, оскільки вони генеруються на платі та вплив на них завад незначний. Другий режим, використовувався для додавання напруг і в подальшому інвертування. Схема побудована таким чином, аби спочатку додати позитивні коефіцієнти, для того щоб на наступному кроці можна було додати всі від’ємні коефіцієнти та інвертовані коефіцієнти з подальшою інверсію. І в самому кінці відбувалася інверсія сигналу для формування диференційної пари Z. Деякі деталі зображені на рисунку. Наприклад, спосіб обчислення резисторів та обчислення теоретичної вихідної напруги описані в текстових блоках. Після обчислення опору були зведені до номіналів та змінений опір записувався в моделях резисторів в Micro-Cap.

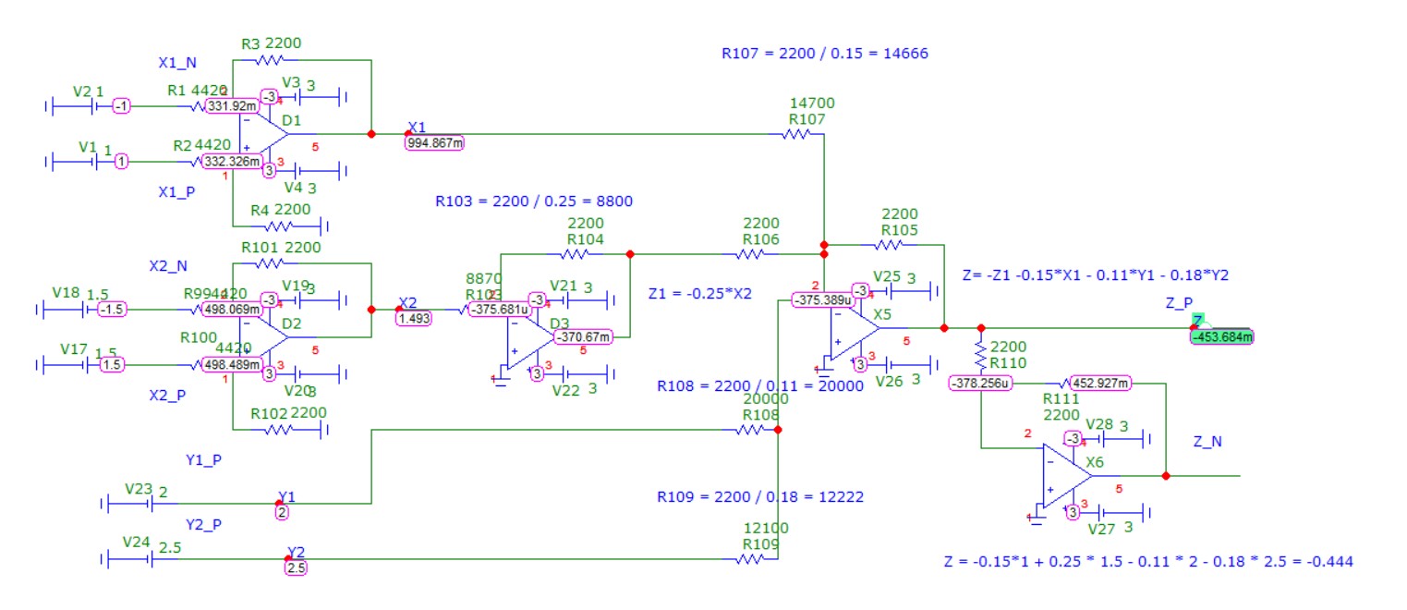
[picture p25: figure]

Рисунок 8.1 — Моделювання аналогових обчислень в Micro-Cap

Рисунок 8.2 — Часові діаграми сигналів попередньої схеми
Далі оберемо операційні підсилювачі, що будемо використовувати на друкованій платі, інформація про них є на рисунку 8.3. Далі перенесемо попередньо розроблену схему програми Micro-Cap на логічну схему Altium CircuitMaker (рисунок 8.4).

Рисунок 8.3 — Інформація про використаний операційний підсилювач

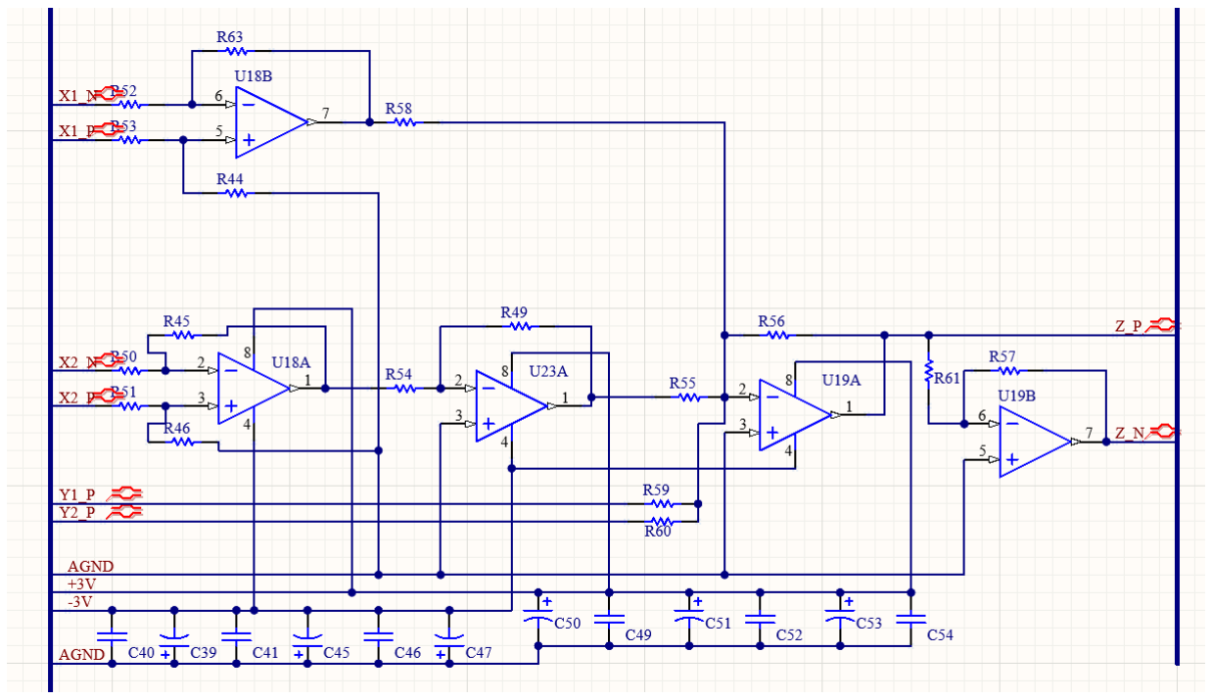
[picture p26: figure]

Рисунок 8.4 — Проектування аналогових обчислень на друкованій платі

### 9. РОЗРОБКА ДРУКОВАНОЇ ПЛАТИ

А тепер нарешті перейдемо до проектування друкованої плати та розміщення всіх компонентів із логічних схем. Спочатку з налаштуємо 4 шари друкованої плати та отвори між шарами (рисунок 9.1). Також налаштуємо розміри для диференційних пар (рисунок 9.2) для забезпечення необхідного хвильового опору.

Рисунок 9.1 — Проектування шарів у друкованої плати

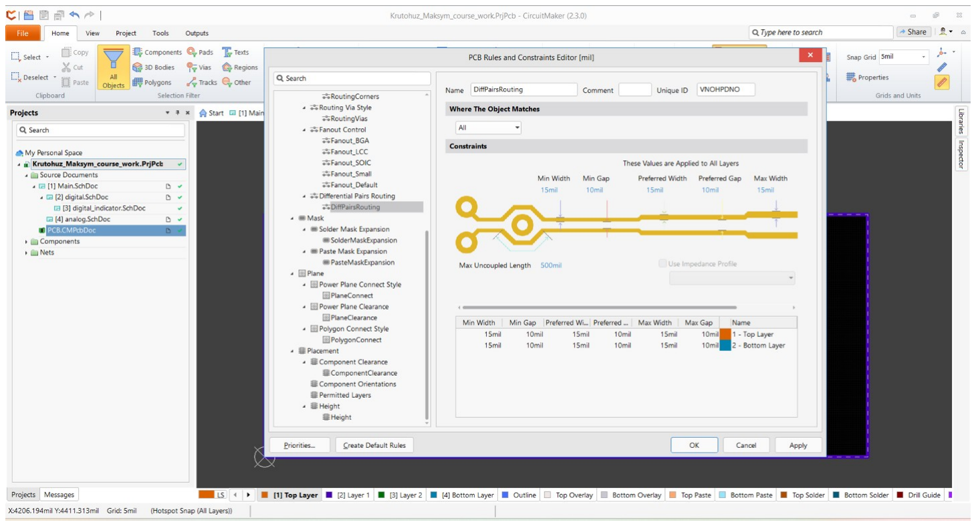
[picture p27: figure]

Рисунок 9.2 — Налаштування правил диференційних пар
Тепер імпортуємо всі компоненти у файл друкованої плати, використовуючи кнопку імпортувати зміни. Після перевірки коректності змін, вони розміщаються біля плати автоматично рисунок 9.3. Далі розмістимо їх на платі, розміщаючи біля кожної мікросхеми розв’язуючий конденсатор для стабілізації напруги в неї (рисунок 9.4).

Рисунок 9.3 — Імпортування логічних компонентів на плату

Рисунок 9.4 — Розміщення компонентів на платі із розв’язуючими конденсаторами
Також приймемо до уваги, що компоненти аналогової та цифрової схеми, розмістимо острівцями (рисунок 9.5). Диференційні пари будемо проводити поруч один до одного (рисунок 9.6).

Рисунок 9.5 — Розміщення елементів аналогової схеми в окремій частині плати

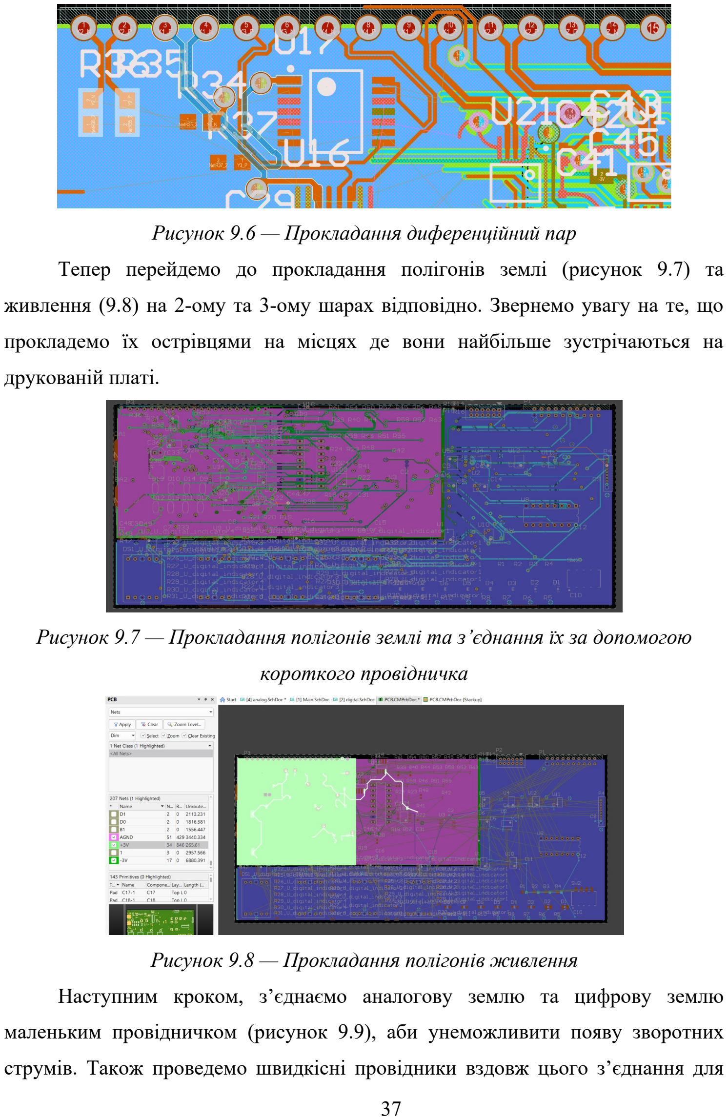
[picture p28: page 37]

Рисунок 9.6 — Прокладання диференційний пар Тепер перейдемо до прокладання полігонів землі (рисунок 9.7) та живлення (9.8) на 2-ому та 3-ому шарах відповідно. Звернемо увагу на те, що прокладемо їх острівцями на місцях де вони найбільше зустрічаються на друкованій платі.

Рисунок 9.7 — Прокладання полігонів землі та з’єднання їх за допомогою короткого провідничка

Рисунок 9.8 — Прокладання полігонів живлення Наступним кроком, з’єднаємо аналогову землю та цифрову землю маленьким провідничком (рисунок 9.9), аби унеможливити появу зворотних струмів. Також проведемо швидкісні провідники вздовж цього з’єднання для забезпечення найменшого хвильового опору на великих частотах. Для виправлення помилки короткого замикання між провідниками аналогової землі та цифрової землі додамо додаткове правило дизайну (рисунок 9.10).

Рисунок 9.9 — Прокладання швидкісних провідників паралельно двом земель вздовж маленького провідничка, що з’єднує їх

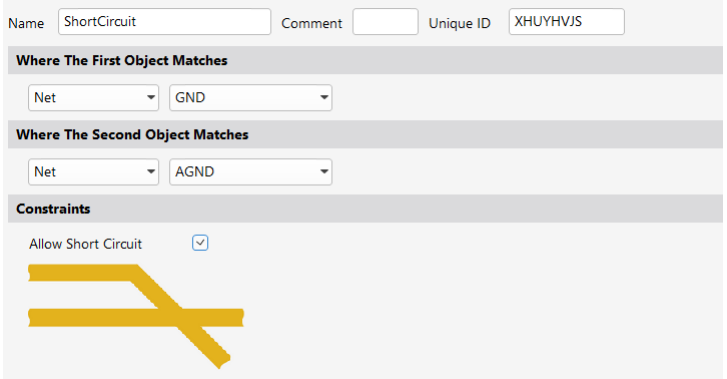
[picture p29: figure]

Рисунок 9.10 — Виправлення помилки щодо короткого замикання двох земель Після прокладання важливих провідників вручну, далі за допомогою автоматичного трасування прокладемо інші провідники, які не проведуться проведемо вручну.
Отже після всіх маніпуляцій над друкованої плати отримуємо результат, який зображений на рисунку 9.11.

Рисунок 11 — Фінальний результат проектування друкованої плати

ВИСНОВКИ

В даній роботі концентрувалися на таких речах: шина SPI, ЦАП, АЦП, аналогові обчислення, використання матричною клавіатури, використання 7-сегментного дисплею і врешті-решт розміщення всіх компонентів та розробка друкованою плати.
Технологія SPI допомагає економити кількість проводів. Наприклад, можна передати сигнал по одному проводі, а потім кожний контакт підключити до світлодіоду, і будемо мати повний контроль над усіма світлодіодами.
Вивід інформації на світлодіод здійснювалося за допомогою шини SPI, вибір світлодіодів ретельно обирався: струм в світлодіодах для світіння потрібен був трішки перебільшувати необхідний для світіння. Причина цьому, якщо світлодіод світиться опір його зменшується та він ще нагрівається, що може спричинити його збій. Також, потрібно звертати на клімат в якому цей світлодіод буде працювати, наприклад в країнах із жарким кліматом, світлодіод має більший ризик, що він вийде із ладу.
Перейдемо | до | аналізу | матричної | клавіатури. | Для | розробки
використовували метод, який допомагає зменшити кількість контактів: замість проведення провідника до кожного рядка, можна опитувати клавіатуру по рядкам, що може зменшити кількість проводів, особливо для великої матричної клавіатури. Слід звернути увагу, що при множинному опитування клавіш, якщо не підключити діоди біля кожної клавішу можливий хибне спрацювання.
Розглянемо | моделювання | індикатора | цифри. | По-перше, | тут
використовувалася технологія SPI і після запису в регістру, інформація переходить в регістр-защіпку, що дозволяє нівелювати миготіння світлодіодних сегментів, що сприймається легше оком людини.
І нарешті поговоримо щодо ЦАП. Оскільки наші комп’ютери цифрові і якщо необхідно вивести напругу, яка може змінюватися в певних межах, виникає потреба у використання цих перетворювачів. Але якщо є потреба виведення аналогового сигналу на великі відстані, вплив на сигнал завад стає більш суттєвим, що змушує використовувати диференційні пари: сигнал в диференційних парах передається на абсолютним значенням, а чим більша різниця між сигналами тим більший сигнал.
А тепер розглянемо АЦП. Тут схожа ситуація як із ЦАП, але навпаки і з певними зауваженнями. По-перше, вихід АЦП потребує стабілізації. В цій роботі для схеми стабілізації, використовувався регульований стабілізатор напруги: дозволяє тримати напругу або струм в певному значені в незалежності зміни навантаження.
Також в цій роботі, використовувалися операційні підсилювачі для аналогових обчислень: додавання та віднімання. По-перше, необхідно використовувати диференційні пари, якщо є потреба передавати аналоговий сигнал на великі відстані в цьому випадку використовувалися операційні підсилювачі в режимі віднімання. По-друге, операційний підсилювач у режимі додавання інвертує сигнал на протилежний, тому потрібно це враховувати для проектування схеми обчислення якогось виразу. По-третє, в залежності від опорів резисторів, які підключені до операційних підсилювачів є змога опрацьовувати кожний сигнал із своїм коефіцієнтом.
І нарешті, перейдемо до аналізу проектування друкованої плати. По-перше для забезпечення необхідного хвильового опору диференційним пар, потрібно визначити відстань між диференційними парами та їх ширину. По-друге, для нівелювання завад в живлені необхідно підключати розв’язуючі конденсатори біля живлення кожної мікросхеми. По-третє, аналогові схеми та цифрові схеми краще розділити та розмістити на різних частинах платах. Оскільки вони використовують різні землі, розміщення їх поруч із своїм полігоном землі, може знизити кількість завад, які будуть виникати на друкованій платі. По-четверте, для унеможливлення протікання зворотних струмів по платах, з’єднаємо полігони різних земель за допомогою тонкого провідничка.

СПИСОК ВИКОРИСТАНИХ ДЖЕРЕЛ

1. Освітній сайт кафедри системного програмування і спеціалізованих комп'ютерних систем факультету прикладної математики КПІ ім. Ігоря Сікорського: Вхід до сайту. Освітній сайт кафедри системного програмування і спеціалізованих комп'ютерних систем факультету прикладної математики КПІ ім. Ігоря Сікорського. URL: https://scs-kpi.pp.ua/course/view.php?id=100 (дата звернення: 02.01.2025).
2. Освітній сайт кафедри системного програмування і спеціалізованих комп'ютерних систем факультету прикладної математики КПІ ім. Ігоря Сікорського: Вхід до сайту. Освітній сайт кафедри системного програмування і спеціалізованих комп'ютерних систем факультету прикладної математики КПІ ім. Ігоря Сікорського. URL: https://scs-kpi.pp.ua/course/view.php?id=100 (дата звернення: 02.01.2025).
3. https :// www. ti. com / lit / ds / symlink / sn 74 hc 595. pdf
4. https :// www. mouser. com / ProductDetail / Nexperia /74 HC 595 BQ 115?
qs = P 62 ublwmbi 8 j 5 S 0 PfJaZ 3 g %3 D %3 D
5. https :// www. mouser. com / ProductDetail / Vishay - Semiconductors / TDSR 1360? qs =%2 Fjqivxn 91 cdefUhhpbnIWA %3 D %3 D (https://www.mouser.com/ProductDetail/Vishay-Semiconductors/TDSR1360?qs=%2Fjqivxn91cdefUhhpbnIWA%3D%3D)

ДОДАТОК А. ЕЛЕКТРОННІ СХЕМИ

Рисунок А.1 – Загальна схема (файл Main.SchDoc)

Рисунок А.2 – Цифрова схема (файл digital.SchDoc)

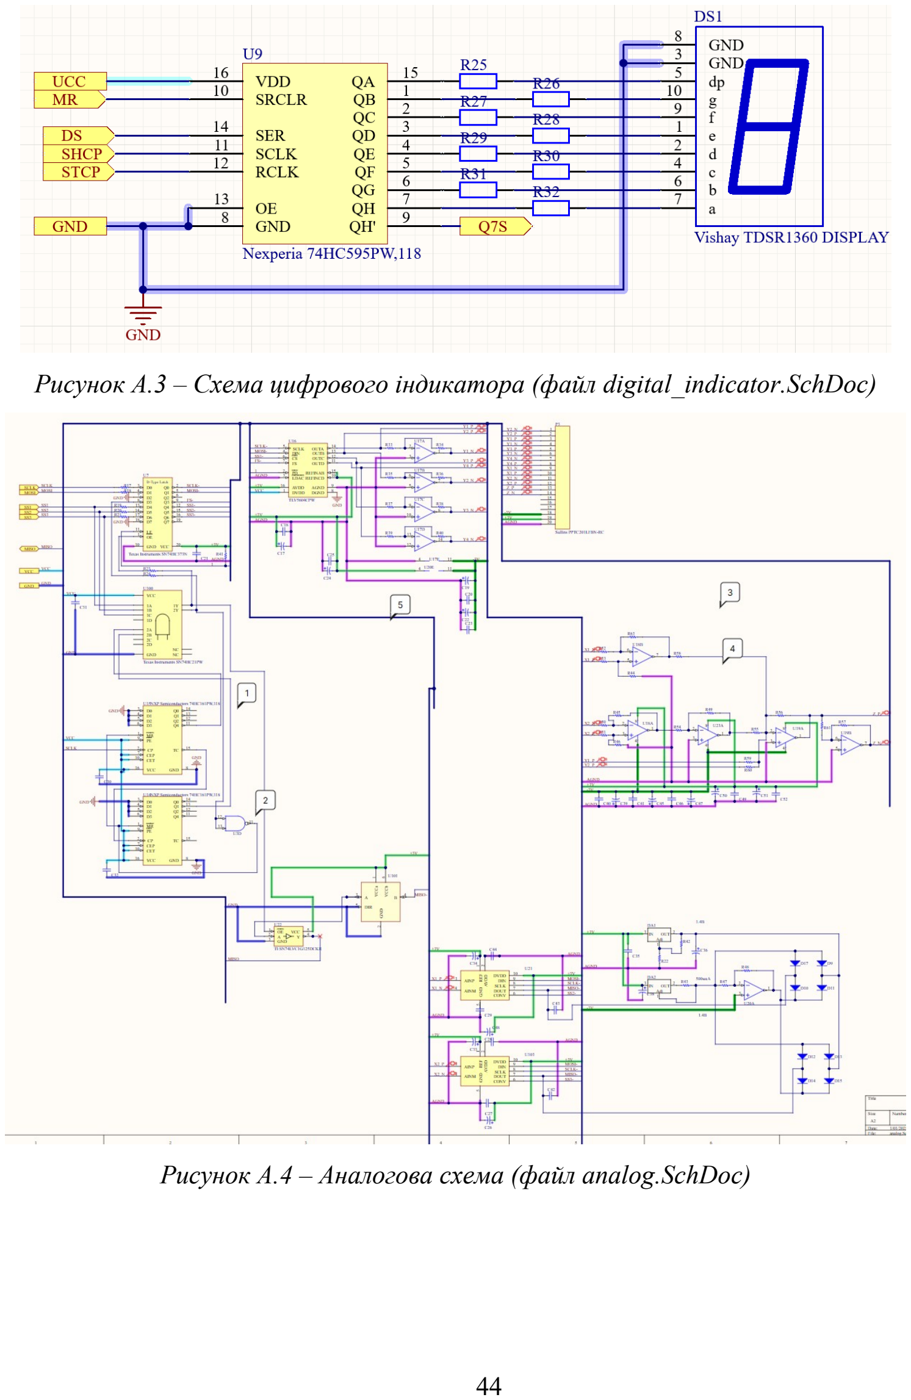
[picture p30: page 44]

Рисунок А.3 – Схема цифрового індикатора (файл digital_indicator.SchDoc)

Рисунок А.4 – Аналогова схема (файл analog.SchDoc)

ДОДАТОК Б. ПЕРЕЛІК ЕЛЕМЕНТІВ

Таблиця Б.1 – Перелік елементів
Назва | Опис | Позначення | Кількість
Murata GRM188R60J2 26MEA0J | 0603 6.3 V 22 uF ±20% Tolerance X5R SMT Multilayer Ceramic Chip Capacitor | C1, C2, C3, C4, C5, C6, C7, C8, C9, C10, C11, C12, C13, C14, C15, C16 | 16
Kemet T491A106K010 AT | Cap Tant Solid 10uF 10V A CASE 10% (3.2 X 1.6 X 1.6mm) SMD 3216-18 3.8 Ohm 125C T/R | C17, C19, C22, C24, C26, C28, C33, C34, C39, C45, C47, C50, C51 | 13
Samsung CL05B104KP5 NNNC | CL05 Series 0.1 uF 10 V ±10 % Tolerance X7R SMT Multilayer Ceramic Capacitor | C18, C20, C21, C23, C25, C27, C29, C30, C31, C32, C35, C40, C41, C46, C49, C52 | 16
Würth Elektronik 860020672005 | Aluminium Electrolytic Capacitor, WCAP-ATG5 Series, 1 F, 20%, 50 V, 5 mm, Radial Leaded | C36 | 1
Rubycon 16PX10000ME FC16X31.5 | Cap Aluminum Lytic 10000uF 16V 20% (16 X 31.5mm) Radial 7.5mm 1950mA 2000h 105°C Bulk | C37 | 1
Nichicon AEC UZR1H0R1MC L1GB | Aluminum Electrolytic Capacitors - SMD 50volts 0.1uF 85c 4X3.9 | C38 | 1
Murata GRM0335C1H | Multilayer Ceramic Capacitors MLCC - | C42, C43 | 2

200JA01D | SMD/SMT 0201 20pF 50volts C0G +/-5%
Taiyo Yuden JMK105BJ105 KV-F | Cap Ceramic 1uF 6.3V X5R 10% SMD 0402 85Â°C Paper T/R | C44, C48 | 2
panorami x APTD2012LSY CK | LED Uni-Color SB. Yellow 590nm 2-Pin Chip LED T/R | D1, D2 | 2
Kingbrig ht APTD2012LZG CK | Standard LEDs; SMD 0810 Dome Lens LED; 2.0x1.2 mm; Green; (Cut Reel) | D3, D4, D5 | 3
Kingbrig ht APTD2012LSU RCK | Standard LEDs; SMD 0806 Dome Lens LED; 2.0x1.2 mm; Red; (Cut Reel) | D6, D7, D8 | 3
ON Semiconductor ES1JFL | Diode Ultra Fast Rectifier 600V 1A 2-Pin SOD-123F T/R | D9, D10, D11, D12, D13, D14, D15, D17 | 8
LM317B D2TG | Linear Voltage Regulator, Positive, Adjustable Output, 1.5 A TJ = -40° to +125°C | DA1, DA2 | 2
Vishay TDSR1360 DISPLAY | LED; 280 ucd (Min.) @ 1 mA; 650 nm (Typ.) @ 1 mA; 1.8 V (Typ.) @ 1 mA; 5 V; | DS1_$ChannelN ame, DS1_$ChannelName, DS1_$ChannelName, DS1_$ChannelName | 4

Sullins SFH11-PBPC-D10-ST-BK | 20 Position Total Dual Row 2.54 mm Pitch Straight Female Box Header | P1 | 1
Molex 87831-1220 | Conn Shrouded Header (4 Sides) HDR 12 POS 2mm Solder ST Top Entry Thru-Hole Milli-Grid™ Tube | P2 | 1
Sullins PPTC201LFBN -RC | 20 Position Header Connector 0.100" (2.54mm) Through Hole Tin | P3 | 1
Molex 53047-1010 | Headers & Wire Housings VERTICAL HDR 10P | P4 | 1
Yageo RC0805FR-071 0KL | Res Thick Film 0805 10K Ohm 1% 0.125W(1/8W) +/-100ppm/C Epoxy Pad SMD T/R | R1, R2, R3, R4 | 4
Vishay Dale CRCW02011K 20FKED | Thick Film Resistors -SMD 1/20watt 1.2Kohms 1% 100ppm | R5, R6, R7, R8, R9, R10, R11, R12 | 8
Vishay Dale CRCW02013K 00FKED | RES SMD 3K OHM 1% 1/20W 0201 | R13, R14, R15, R16 | 4
Yageo RC0402JR-074 K7L | Res Thick Film 1.0 x 0.5 mm 4.7K Ohm 5% 0.063W(1/16W) 100ppm/ C Molded SMD Paper T/R | R17, R18, R19, R20, R21, R23, R24, R41 | 8
Panasonic | Res Thick Film 0603 | R22, R33, R34, | 11

ERJ-S03J222V

2.2K Ohm 5% 1/10W
±200ppm/°C Molded SMD
SMD Punched Carrier T/R

R35, R36, R37, R38,
R39, R40, R47, R48
Uniroyal
0603WAF3300
T5E

CHIP RESISTOR -
SURFACE MOUNT
330OHMS ±1% 1/10W 0603
ROHS

R25_$ChannelN
ame,
R25_$ChannelName,
R25_$ChannelName,
R25_$ChannelName,
R26_$ChannelName,
R26_$ChannelName,
R26_$ChannelName,
R26_$ChannelName,
R27_$ChannelName,
R27_$ChannelName,
R27_$ChannelName,
R27_$ChannelName,
R28_$ChannelName,
R28_$ChannelName,
R28_$ChannelName,
R28_$ChannelName,
R29_$ChannelName,
R29_$ChannelName,
R29_$ChannelName,
R29_$ChannelName,
R30_$ChannelName,
R30_$ChannelName,
R30_$ChannelName,
R30_$ChannelName,
R31_$ChannelName,
R31_$ChannelName,

32

| | R31_$ChannelName, R31_$ChannelName, R32_$ChannelName, R32_$ChannelName, R32_$ChannelName, R32_$ChannelName
Yageo / Phycomp RC0402FR-076 8KL | RES SMD 68K OHM 1% 1/16W 0402 | R42 | 1
Yageo / Phycomp RC0402FR-072 K4L | RES SMD 2.4K OHM 1% 1/16W 0402 | R43 | 1
Panasonic ERJ-2RKF2201 X | Precision resistor, SMD [Panasonic Automotive & Industrial Systems] ERJ2RKF2201X Precision resistor, SMD | R44, R45, R46, R49, R55, R56, R57, R61, R63 | 9
Yageo / Phycomp RC0402FR-074 K42L | Thick Film Resistors -SMD 4.42K OHM 1% | R50, R51, R52, R53 | 4
Vishay Dale CRCW04028K 87FKED | Thick Film Resistors -SMD 1/16watt 8.87Kohms 1% 100ppm | R54 | 1
Panasonic ERJ-2RKF1472 X | Thick Film Resistors -SMD 0402 14.7Kohms 1% Tol | R58 | 1

Vishay Dale CRCW040220 K0FKED | RES SMD 20K OHM 1% 1/16W 0402 | R59 | 1
Stackpole Electronics RMCF0603FT1 2K1 | Res Thick Film 0603 12.1k Ohm 1% 1/10W ±100ppm/°C Molded SMD Paper T/R | R60 | 1
Arun -CTS Components 219-4MSTR | Switch DIP ON OFF SPST 4 Raised Slide 0.1A 20VDC Gull Wing 2000Cycles 2.54mm SMD T/R | SW2 | 1
NXP Semiconductors 74HC161PW,11 8 | Counter Single 4-Bit Sync Binary UP 16-Pin TSSOP T/R | U1, U2, U14, U15 | 4
Texas Instruments SN74HC00PW R | 74HC00 quad NAND gate TSSOP 14 | U3 | 1
Nexperia 74HC165PW,11 8 | 74HC Series 6 V 8-Bit Parallel-In/Serial Out Shift Register - TSSOP-16 | U4, U10, U12 | 3
Nexperia 74HC595PW,11 8 | 74HC(T)595 - 8-bit serial-in, serial or parallel-out shift register with output latches; 3-state | U5, U6, U9_$ChannelName, U9_$ChannelName, U9_$ChannelName, U9_$ChannelName | 6
Texas | Octal Transparent D- | U7 | 1

Instruments SN74HC373N | Type Latches With 3-State Outputs 20-PDIP -40 to 85
Texas Instruments SN74HC139N | Dual 2-Line To 4-Line Decoders/Demultiplexers 16-PDIP -40 to 85 | U8 | 1
Texas Instruments SN74HC125P WR | p | U11 | 1
NXP Semiconductors 74HC151PW-Q100,118 | Multiplexer 1-Element CMOS 8-IN 16-Pin TSSOP T/R | U13 | 1
TLV5604 CPW | 10-Bit, 3 us Quad DAC, Serial Input, Simultaneous Update, Programmable Settling Time, Power Down, 0 to 70 degC, 16-pin SOP (PW16), Green (RoHS & no Sb/Br) | U16 | 1
Microchi p MCP6004T-I/ST | MCP6004 Series 6 V 1 MHz SMT Low-Power Operational Amplifier -TSSOP-14 | U17, U20 | 2
MCP600 2-I/SN | 1 MHz, Low-Power Operational Amplifier, 8-Pin SOIC, Industrial Temperature | U18, U19, U23 | 3
Texas Instruments ADS8867IDGS | Single Channel Single ADC SAR 100ksps 16-bit Serial 10-Pin VSSOP T/R | U21, U103 | 2

R
TI SN74LVC1G12 5DCKR | Buffer/Line Driver 1-CH Non-Inverting 3-ST CMOS Medical 5-Pin SC-70 T/R | U22 | 1
Texas Instruments SN74HC21PW | AND Gate 2-Element 4-IN CMOS 14-Pin TSSOP Tube | U100 | 1
Nexperia 74LVC1T45G W,125 | 74LVC1T45; 74LVCH1T45 - Dual supply translating transceiver; 3-state | U101 | 1

ДОДАТОК В. ДРУКОВАНА ПЛАТА

Рисунок В.1 – Друкована плата, шар Top Layer

Рисунок В.2 – Друкована плата, шар Layer 1

Рисунок В.3 – Друкована плата, шар Layer 2

Рисунок В.4 – Друкована плата, шар Bottom Layer

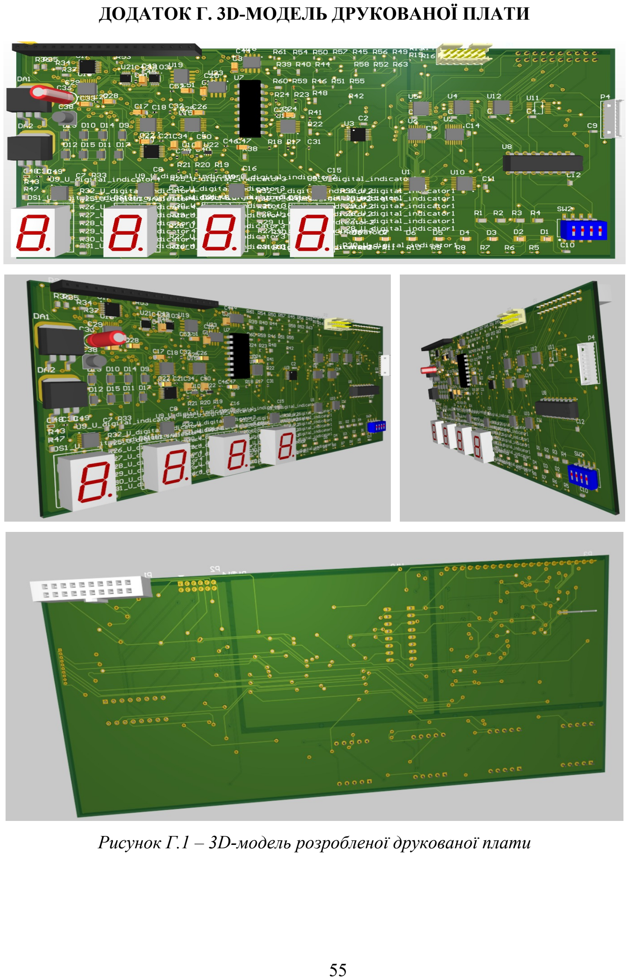
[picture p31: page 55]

ДОДАТОК Г. 3D-МОДЕЛЬ ДРУКОВАНОЇ ПЛАТИ

Рисунок Г.1 – 3D-модель розробленої друкованої плати

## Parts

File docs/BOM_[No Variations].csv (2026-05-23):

Comment | Description | Designator | Footprint | LibRef | Quantity
Murata GRM188R60J226MEA0J | 0603 6.3 V 22 uF ±20% Tolerance X5R SMT Multilayer Ceramic Chip Capacitor | C1, C2, C3, C4, C5, C6, C7, C8, C9, C10, C11, C12, C13, C14, C15, C16 | PCB-0lt2tlorldzk7b1ikz7j-1 | CMP-0406ccc3fa2ddbc1-1 | 16
Kemet T491A106K010AT | Cap Tant Solid 10uF 10V A CASE 10% (3.2 X 1.6 X 1.6mm) SMD 3216-18 3.8 Ohm 125C T/R | C17, C19, C22, C24, C26, C28, C33, C34, C39, C45, C47, C50, C51 | PCB-z1fsktxgkyvo6s7hhrmp-1 | CMP-e2d92bd252d93d1e-2 | 13
Samsung CL05B104KP5NNNC | CL05 Series 0.1 uF 10 V ±10 % Tolerance X7R SMT Multilayer Ceramic Capacitor | C18, C20, C21, C23, C25, C27, C29, C30, C31, C32, C35, C40, C41, C46, C49, C52 | PCB-wdo14ufqtx9e5lciolxc-1 | CMP-97145e617dc648d3-3 | 16
Würth Elektronik 860020672005 | Aluminium Electrolytic Capacitor, WCAP-ATG5 Series, 1 F, 20%, 50 V, 5 mm, Radial Leaded | C36 | PCB-h0tpes09f84bylb2e008-1 | CMP-b941737d36536686-1 | 1
Rubycon 16PX10000MEFC16X31.5 | Cap Aluminum Lytic 10000uF 16V 20% (16 X 31.5mm) Radial 7.5mm 1950mA 2000h 105°C Bulk | C37 |  | CMP-3388fbb31d24ec4f-4 | 1
Nichicon AEC UZR1H0R1MCL1GB | Aluminum Electrolytic Capacitors - SMD 50volts 0.1uF 85c 4X3.9 | C38 | Nichicon AEC UZR1H0R1MCL1GB-Footprint-1 | CMP-101531-5 | 1
Murata GRM0335C1H200JA01D | Multilayer Ceramic Capacitors MLCC - SMD/SMT 0201 20pF 50volts C0G +/-5% | C42, C43 | CAPC1005X56X25ML10T15 | CMP-3573569-4 | 2
Taiyo Yuden JMK105BJ105KV-F | Cap Ceramic 1uF 6.3V X5R 10% SMD 0402 85Â°C Paper T/R | C44, C48 | PCB-j2ftjotvcug85tkm51ob-1 | CMP-92075b0eb03e4dc0-1 | 2
panoramix APTD2012LSYCK | LED Uni-Color SB. Yellow 590nm 2-Pin Chip LED T/R | D1, D2 | Kingbright APTD2012LSYCK-Footprint-1 | CMP-3ae3f73e6e52e524-1 | 2
Kingbright APTD2012LZGCK | Standard LEDs; SMD 0810 Dome Lens LED; 2.0x1.2 mm; Green; (Cut Reel) | D3, D4, D5 | PCB-w3xds7ygkg7mnhc1cmmw-1 | CMP-f2943f49a62b2d53-1 | 3
Kingbright APTD2012LSURCK | Standard LEDs; SMD 0806 Dome Lens LED; 2.0x1.2 mm; Red; (Cut Reel) | D6, D7, D8 | PCB-iw7n8hwpuzl09snnxv9p-1 | CMP-10e0dd3d4450cf27-1 | 3
ON Semiconductor ES1JFL | Diode Ultra Fast Rectifier 600V 1A 2-Pin SOD-123F T/R | D9, D10, D11, D12, D13, D14, D15, D17 | PCB-n4d7strh02ppfuecjec7-1 | CMP-d18f1b0cb91f0e48-4 | 8
LM317BD2TG | Linear Voltage Regulator, Positive, Adjustable Output, 1.5 A TJ = -40° to +125°C | DA1, DA2 | PCBComponent_1 - duplicate | CMP-15eddce85befca2a-4 | 2
Vishay TDSR1360 DISPLAY | LED; 280 ucd (Min.) @ 1 mA; 650 nm (Typ.) @ 1 mA; 1.8 V (Typ.) @ 1 mA; 5 V; | DS1_$ChannelName | PCB-wjfw9shywxa82n8451hf-1 | CMP-7c47b7143e56a380-9 | 4
Sullins SFH11-PBPC-D10-ST-BK | 20 Position Total Dual Row 2.54 mm Pitch Straight Female Box Header | P1 | PCB-83mps1k0gqada0l58a0x-1 | CMP-9fd6561db1f14011-1 | 1
Molex 87831-1220 | Conn Shrouded Header (4 Sides) HDR 12 POS 2mm Solder ST Top Entry Thru-Hole Milli-Grid™ Tube | P2 | PCB-6vf2p1s9ekmr7d72yzhx-1 | CMP-d9471049c6620680-1 | 1
Sullins PPTC201LFBN-RC | 20 Position Header Connector 0.100" (2.54mm) Through Hole Tin | P3 | PCB-z0ty6rx85lga4uhy8mfk-1 | CMP-1abcd3b21d61c57b-4 | 1
Molex 53047-1010 | Headers & Wire Housings VERTICAL HDR 10P | P4 | PCB-2481956-1 | CMP-2481956-4 | 1
Yageo RC0805FR-0710KL | Res Thick Film 0805 10K Ohm 1% 0.125W(1/8W) +/-100ppm/C Epoxy Pad SMD T/R | R1, R2, R3, R4 | PCB-9100704-1 | CMP-1854303-39 | 4
Vishay Dale CRCW02011K20FKED | Thick Film Resistors - SMD 1/20watt 1.2Kohms 1% 100ppm | R5, R6, R7, R8, R9, R10, R11, R12 | RESC0603X28X15NL05T05 | CMP-1859820-2 | 8
Vishay Dale CRCW02013K00FKED | RES SMD 3K OHM 1% 1/20W 0201 | R13, R14, R15, R16 | RESC0603X28X15LL05T05 | CMP-1859822-2 | 4
Yageo RC0402JR-074K7L | Res Thick Film 1.0 x 0.5 mm 4.7K Ohm 5% 0.063W(1/16W) 100ppm/ C Molded SMD Paper T/R | R17, R18, R19, R20, R21, R23, R24, R41 | RESC1005X04N | CMP-c8d801c1cfb1171f-2 | 8
Panasonic ERJ-S03J222V | Res Thick Film 0603 2.2K Ohm 5% 1/10W ±200ppm/°C Molded SMD SMD Punched Carrier T/R | R22, R33, R34, R35, R36, R37, R38, R39, R40, R47, R48 | CAPC1608X90X35NL15T15 | CMP-84374f5fe8025bf0-1 | 11
Uniroyal 0603WAF3300T5E | CHIP RESISTOR - SURFACE MOUNT 330OHMS ±1% 1/10W 0603 ROHS | R25_$ChannelName, R26_$ChannelName, R27_$ChannelName, R28_$ChannelName, R29_$ChannelName, R30_$ChannelName, R31_$ChannelName, R32_$ChannelName | 0603WAF3300T5E | CMP-d0361cd0d87d0ff1-1 | 32
Yageo / Phycomp RC0402FR-0768KL | RES SMD 68K OHM 1% 1/16W 0402 | R42 | RESC1005X40X25NL05T10 | CMP-1900174-2 | 1
Yageo / Phycomp RC0402FR-072K4L | RES SMD 2.4K OHM 1% 1/16W 0402 | R43 | RESC1005X40X25NL05T10 | CMP-1853114-2 | 1
Panasonic ERJ-2RKF2201X | Precision resistor, SMD [Panasonic Automotive & Industrial Systems] ERJ2RKF2201X Precision resistor, SMD | R44, R45, R46, R49, R55, R56, R57, R61, R63 | PCB-0lk0bdk11ubuienx11rv-1 | CMP-1e3ed7822610c1f9-2 | 9
Yageo / Phycomp RC0402FR-074K42L | Thick Film Resistors - SMD 4.42K OHM 1% | R50, R51, R52, R53 | RESC1005X40X25LL05T10 | CMP-3694873-2 | 4
Vishay Dale CRCW04028K87FKED | Thick Film Resistors - SMD 1/16watt 8.87Kohms 1% 100ppm | R54 | RESC1005X40X25LL05T05 | CMP-1856837-2 | 1
Panasonic ERJ-2RKF1472X | Thick Film Resistors - SMD 0402 14.7Kohms 1% Tol | R58 | RESC1005X40X25ML05T05 | CMP-3654661-2 | 1
Vishay Dale CRCW040220K0FKED | RES SMD 20K OHM 1% 1/16W 0402 | R59 | PCB-xukofss9ju753iqcqyy1-1 | CMP-1856379-5 | 1
Stackpole Electronics RMCF0603FT12K1 | Res Thick Film 0603 12.1k Ohm 1% 1/10W ±100ppm/°C Molded SMD Paper T/R | R60 | RESC1609X50X30ML10T20 | CMP-4a788257458695bf-1 | 1
Arun -CTS Components 219-4MSTR | Switch DIP ON OFF SPST 4 Raised Slide 0.1A 20VDC Gull Wing 2000Cycles 2.54mm SMD T/R | SW2 | PCB-w5asm2ui77r6y7paijkm-1 | CMP-1766de7912dec8a1-2 | 1
NXP Semiconductors 74HC161PW,118 | Counter Single 4-Bit Sync Binary UP 16-Pin TSSOP T/R | U1, U2, U14, U15 | 74HC161PW | CMP-7ee3b776945ea124-1 | 4
Texas Instruments SN74HC00PWR | 74HC00 quad NAND gate TSSOP 14 | U3 | PCB-km7m6461xupsyu5p8fbn-1 | CMP-1078d9752f36cfbf-5 | 1
Nexperia 74HC165PW,118 | 74HC Series 6 V 8-Bit Parallel-In/Serial Out Shift Register - TSSOP-16 | U4, U10, U12 | PCB-l7v5lpviuh96d6vuhrfj-1 | CMP-d6a61b1d9d060961-1 | 3
Nexperia 74HC595PW,118 | 74HC(T)595 - 8-bit serial-in, serial or parallel-out shift register with output latches; 3-state | U5, U6, U9_$ChannelName | PCB-o242chspmi3els652icb-1 | CMP-284ce1e6cd9cf78b-7 | 6
Texas Instruments SN74HC373N | Octal Transparent D-Type Latches With 3-State Outputs 20-PDIP -40 to 85 | U7 | DIP-16 | CMP-065dcf501350d99a-3 | 1
Texas Instruments SN74HC139N | Dual 2-Line To 4-Line Decoders/Demultiplexers 16-PDIP -40 to 85 | U8 | PCB-ctj26q9zb3sevqagct1v-1 | CMP-00b6c9bc66ecdf71-2 | 1
Texas Instruments SN74HC125PWR | p | U11 | SOP14 | CMP-1de6d4cf9c50c221-3 | 1
NXP Semiconductors 74HC151PW-Q100,118 | Multiplexer 1-Element CMOS 8-IN 16-Pin TSSOP T/R | U13 |  | CMP-e43c2c4f5d0e3bfb-1 | 1
TLV5604CPW | 10-Bit, 3 us Quad DAC, Serial Input, Simultaneous Update, Programmable Settling Time, Power Down, 0 to 70 degC, 16-pin SOP (PW16), Green (RoHS & no Sb/Br) | U16 | TI-PW16_M | CMP-1089223-2 | 1
Microchip MCP6004T-I/ST | MCP6004 Series 6 V 1 MHz SMT Low-Power Operational Amplifier - TSSOP-14 | U17, U20 | PCB-qd5l9gv8ivpyuc7qt6ns-1 | CMP-1324864-8 | 2
MCP6002-I/SN | 1 MHz, Low-Power Operational Amplifier, 8-Pin SOIC, Industrial Temperature | U18, U19, U23 | SOIC-SN8_M | CMP-1319626-5 | 3
Texas Instruments ADS8867IDGSR | Single Channel Single ADC SAR 100ksps 16-bit Serial 10-Pin VSSOP T/R | U21, U103 | PCB-d59p20ac3i2z7mc1g5dw-1 | CMP-3953f19d873ae694-2 | 2
TI SN74LVC1G125DCKR | Buffer/Line Driver 1-CH Non-Inverting 3-ST CMOS Medical 5-Pin SC-70 T/R | U22 | SC-70-5 | CMP-814a4847b2015e8d-9 | 1
Texas Instruments SN74HC21PW | AND Gate 2-Element 4-IN CMOS 14-Pin TSSOP Tube | U100 | PCB-zlibg0os7u66y1b7c6dv-1 | CMP-6615af12324ab9d2-2 | 1
Nexperia 74LVC1T45GW,125 | 74LVC1T45; 74LVCH1T45 - Dual supply translating transceiver; 3-state | U101 | PCB-2kx227qvn7pif93bx96a-1 | CMP-9dea5051caa8422d-3 | 1

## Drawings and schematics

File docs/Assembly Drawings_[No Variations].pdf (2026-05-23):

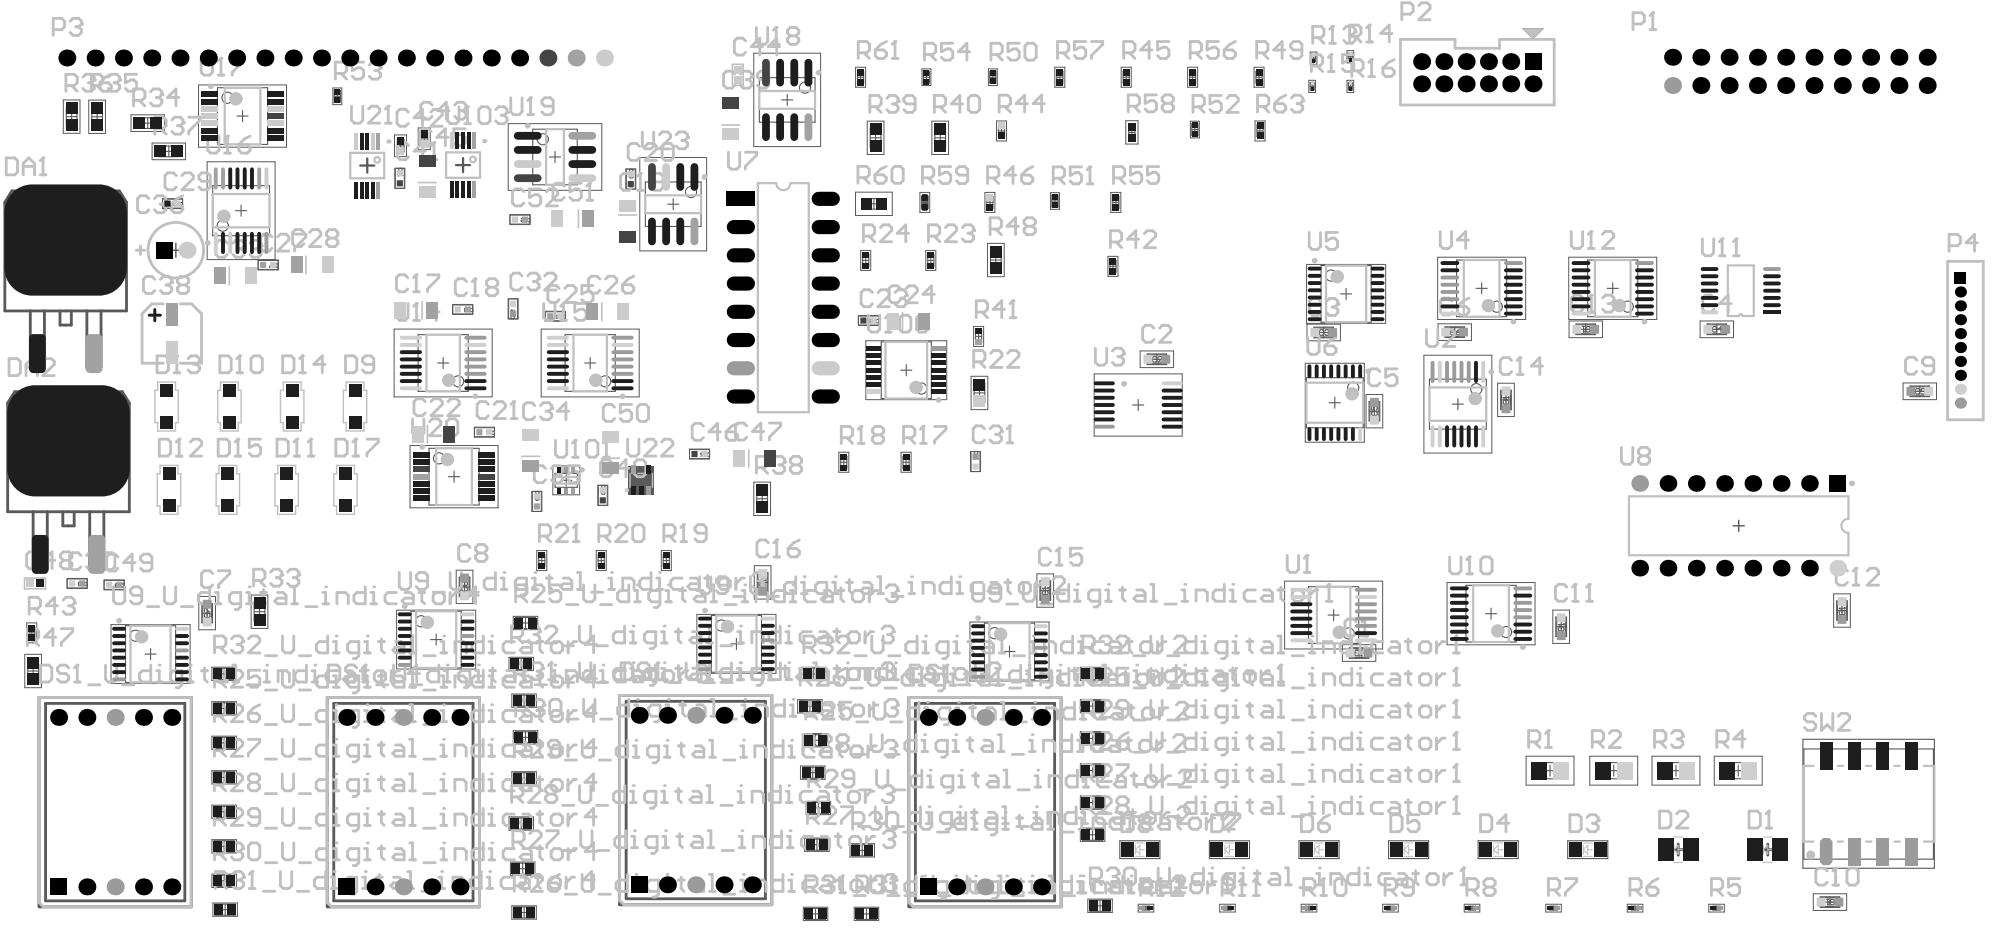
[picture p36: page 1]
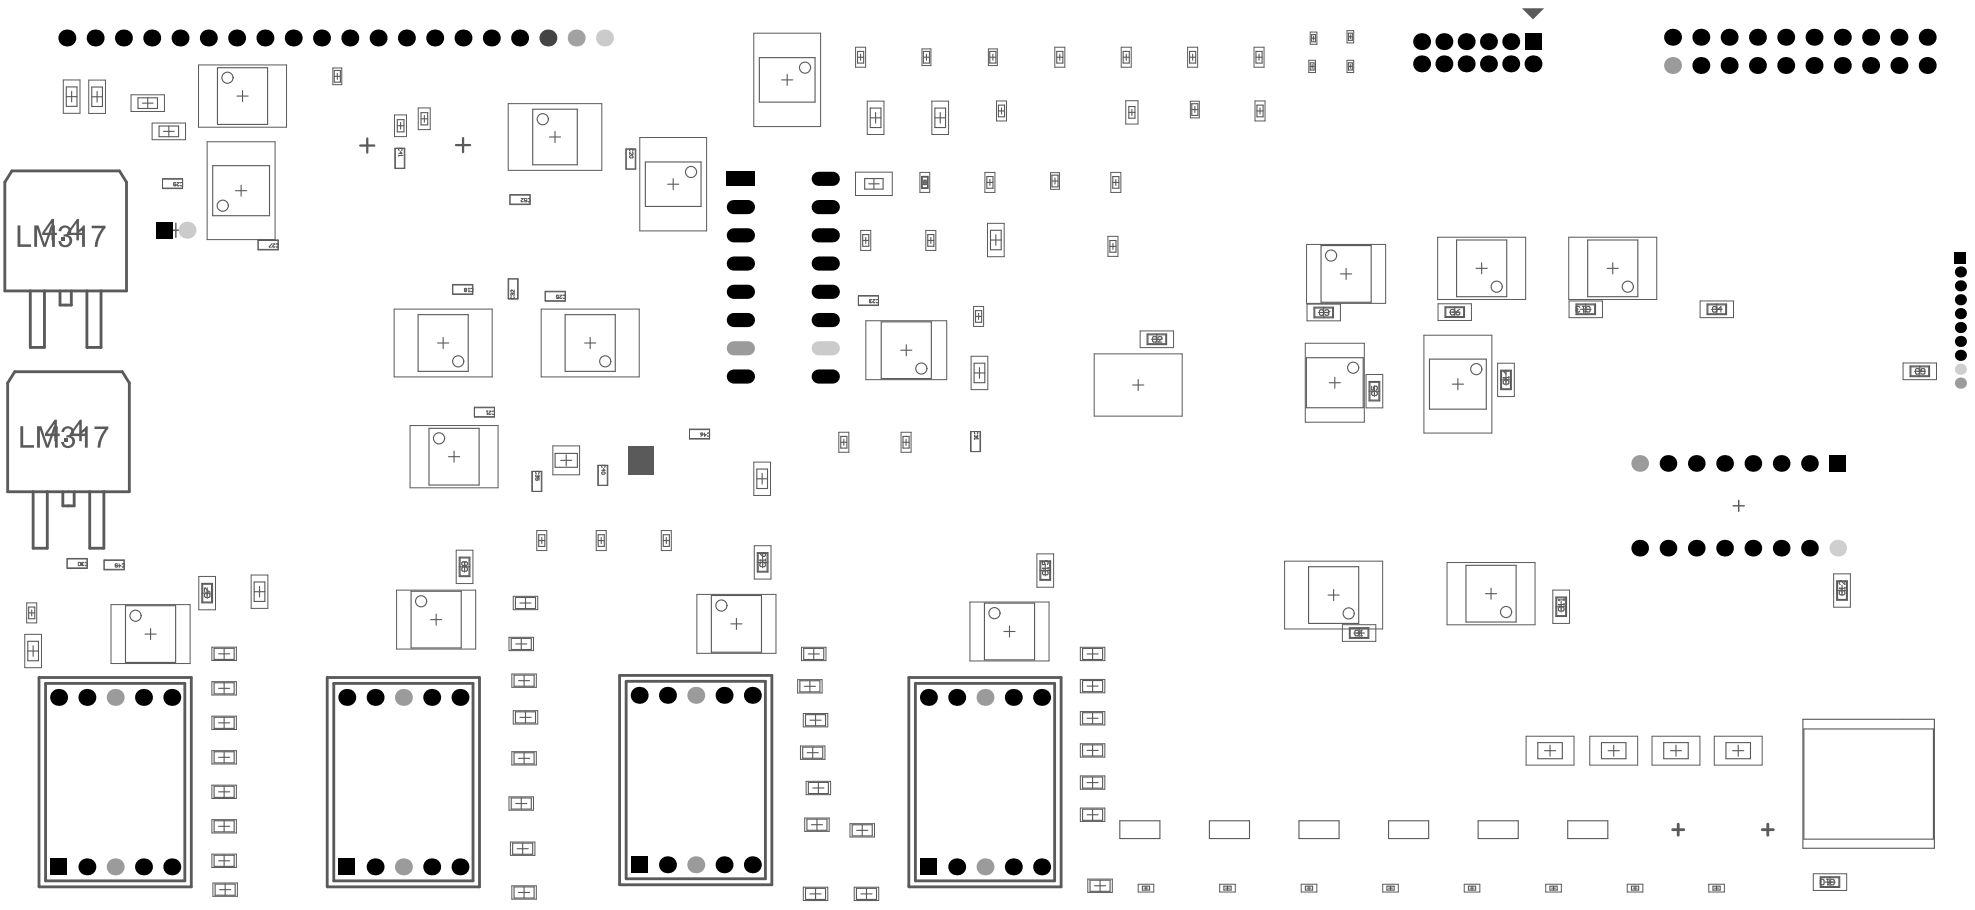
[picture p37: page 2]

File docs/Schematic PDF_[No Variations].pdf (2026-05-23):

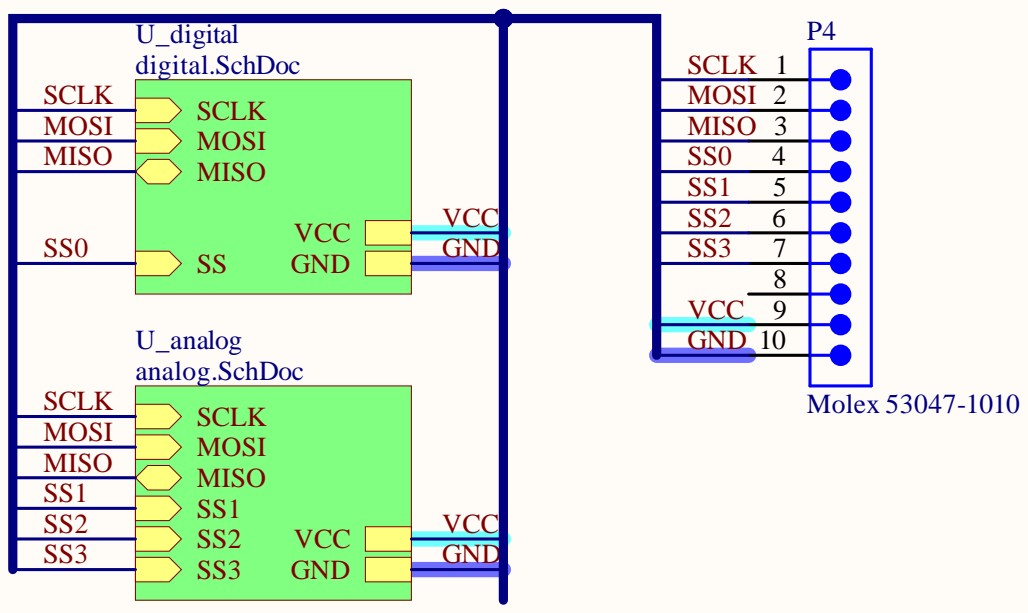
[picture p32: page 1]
VCC GND; SS3 VCC GND

VCC GND

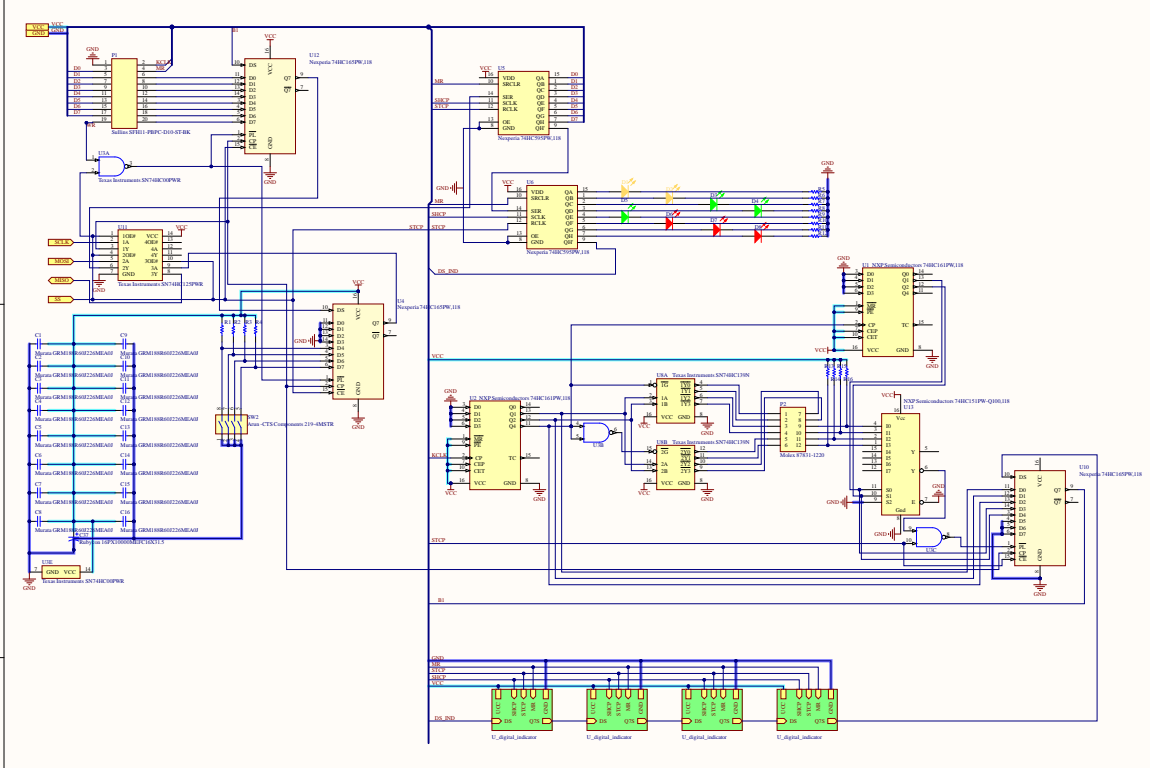
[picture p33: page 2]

Sullins SFH11-PBPC-D10-ST-BK

GND

VDD 16
SRCLR 10 | R6

SHCP

D5 4
D6 5

MR
STCP
VCC

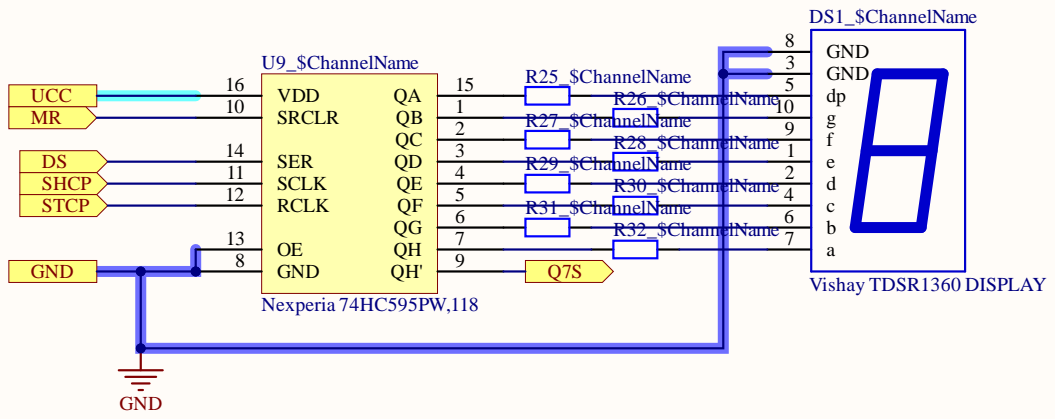
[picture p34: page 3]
STCP GND; PIU90$ChannelName015 PIR250$ChannelName01; PIU90$ChannelName02 PIR270$ChannelName01; PIU90$ChannelName04 PIR290$ChannelName01; PIU90$ChannelName06 PIR310$ChannelName01

R2 8 _ | N ame 1

R2 9 _ | | PIDS10$ChannelName01 PIDS10$ChannelName01 2

R3 0 _ | N ame PIDS10$ChannelName02 PIDS10$ChannelName02 4 PIDS10$ChannelName04 PIDS10$ChannelName04

R3 2 _ | N ame 7

GND 3

VDD 16 | | dp 5
SRCLR 10 | g 10
RCLK 12 SCLK 11 SER 14 OE 13 | R27_$ChannelName | f 9

GND 3

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

GND 3

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

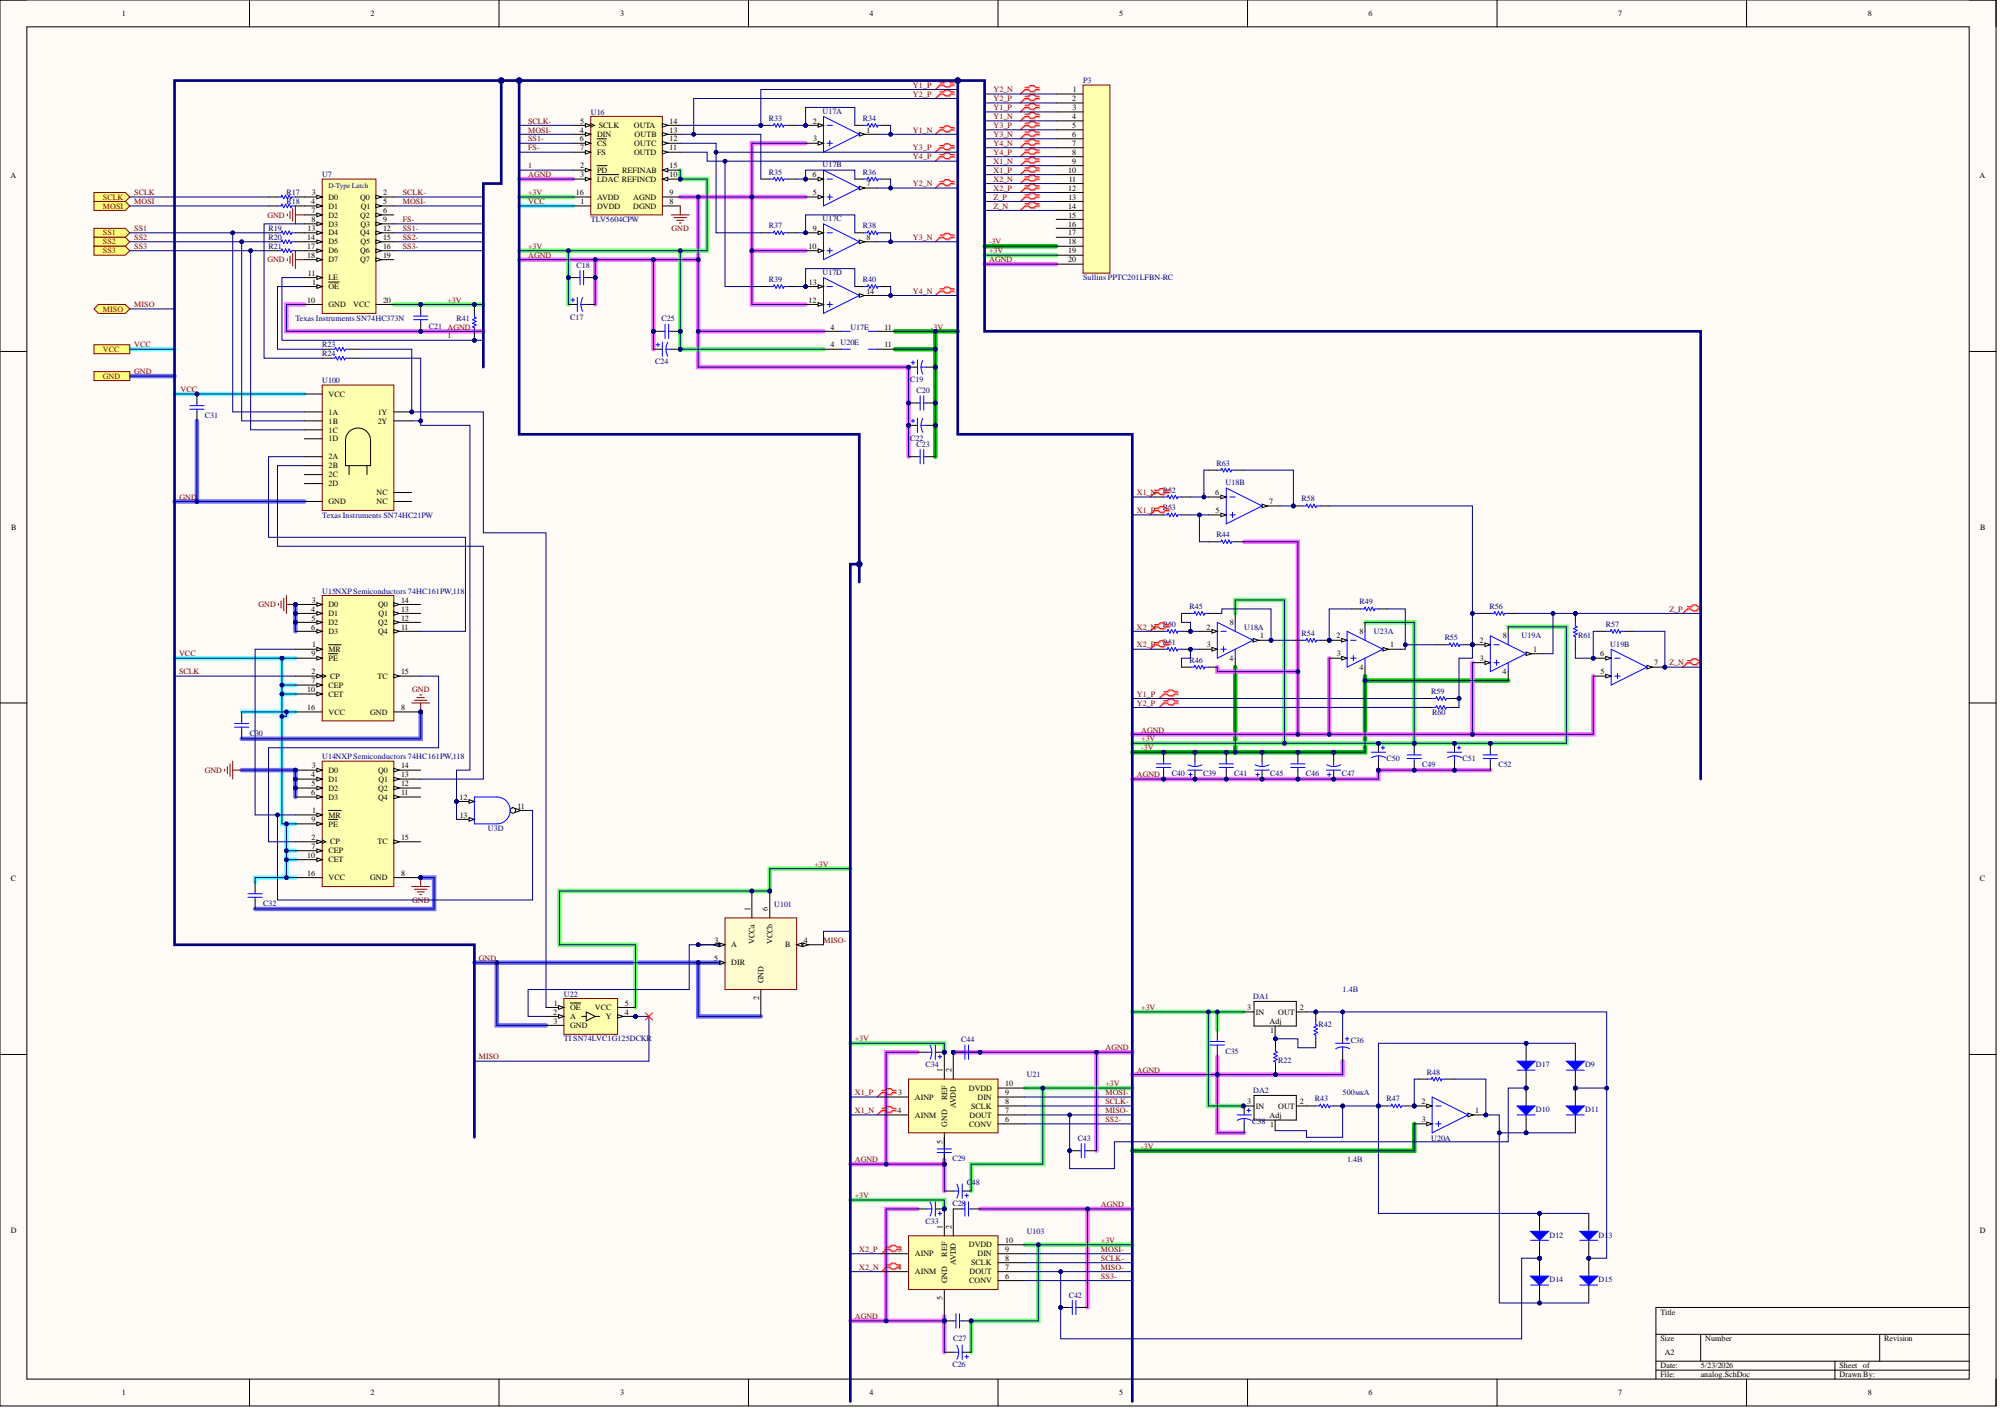
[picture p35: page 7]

MOSI- | | 1 | Y1_N
SS1- | CS 6 | 3
FS- | FS 7 | | | Y3_P

CEP 7 | GND
CET 10

AGND
+3V
-3V

U14NXP Semiconductors 74HC161PW,118

CEP 7

DIR 5

MISO
